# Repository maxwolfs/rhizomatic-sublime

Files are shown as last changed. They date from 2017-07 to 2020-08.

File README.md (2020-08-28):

# The rhizomatic sublime
### Searching for aesthetic transcendence in digital transience
Process and documentation of a research by [Max Wolfs](https://github.com/maxwolfs) and [Alexander Lehmann](https://github.com/bsplt).

### Rhizm

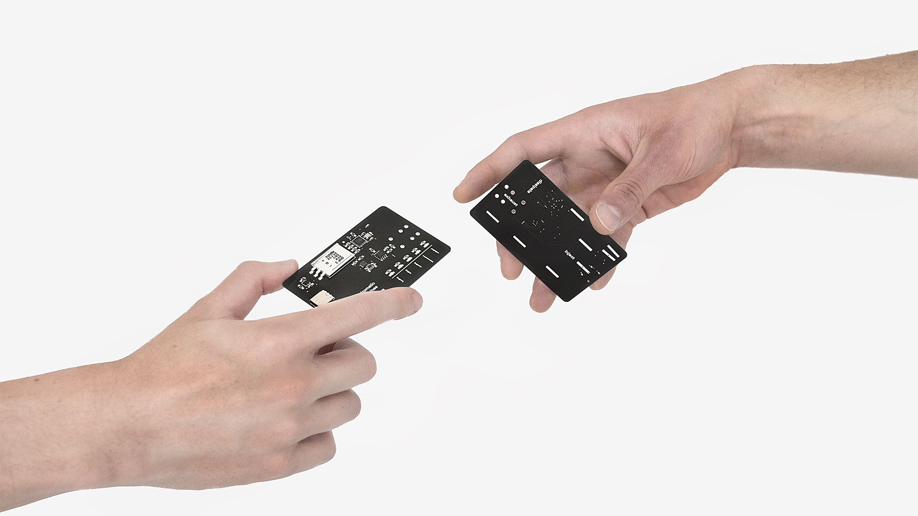
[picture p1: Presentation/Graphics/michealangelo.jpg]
Interaction


We object to the mundane paradigm of Human-Computer-Interaction and demand a Human-Human-Interaction. It's pyhsicial, it's intimate, it's exciting. Rhizm is a device in the shape of a credit card that connects over a satisfying magnetic click. Caution: Hands may touch. The connection of two cards creates a new bond in a decentralized social mesh network. Combined with a web interface that shows the verified encrypted interactions, Rhizm can be used for many different scenarios in which a physicial interaction between nodes must be safe. Or appealing. We understand our project as fundamental research in times of disbelief and scepsis among the realms of new technologies and social media. We want to commit ourselves to the power of open source platforms. Through social sandboxes like Rhizm a diverse variety of use cases such as self deployable social networks depending on real human interactions are possible.

Inject - Exhaust - Dissipate

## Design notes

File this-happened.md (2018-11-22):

# This Happened - Rhizomatic Machines

## Publikum

* Größtenteils Hamburger Werbelandschaft, Kreative, Mitte 30 bis Mitte 40
* 180 Leute + Overbooking
* Deutsch

## Konzept

* Wir objecten zu hci und demanden real hhi - why?
* dafür haben eine neue Interaktion, die ein decenztralized p2p social network established - how?
* Was ist diese Interaktion? - zwei karten klicken auf einander - cautions may touch - its intimate
* wie funktioniert die? - grafik

* Stage Test

* Das ist die Hardware -device

### Presi

1. Anekdote - Herleitung, Persönliche Stickyness zum dahinterliegenden Problem

Dass wir heute hier stehen ist das Ergebnis einer unfallreichen Verkettung von Zufällen.
[FotoMasterStudio]

2. Ausgangspunkt und Problem - Why

[lustigesBild] 
Die Welt ist voller General Purpose Devices samt bedeutungsloser, generischer Gesten.
Es ist leider nicht so wie mit Lichtschaltern, die man blind und in Dunkelheit in Räumen findet und bedienen kann. Denn die immer gleichen, absurden Bewegungen und Gesten [Absurditität mit einem Stück Holz demonstrieren] sind mit den Aktionen die sie auslösen total disconnected.

Der Lichtschalter schaltet Licht ein und aus. Ein Swipe verbindet die sexuelle Absicht zweier Personen, löscht Nachrichten, erzeugt den nächsten Screen oder lehnt den nächsten Anruf ab. Soziale Interaktionen unterscheiden sich in ihrer Bedienbarkeit nicht von Software-Funktionen. Dem Smartphone ist scheißegal ob du deine Oma wegdrückst oder ob du den Wecker stellst. Eine Virtuelle Mechanik die logisch erscheint aber dennoch frei erfunden und sich nur visuell hinter Panzerglas auf einem Bildschirm abspielt. Es ist schon lustig dass ein paar Menschen in Kaliforniern weltweit die Daumen von Milliarden von Menschen utilisiert haben.

[UnserLogoIrgendwie]
Wir widersprechen diesem mondänen HCI Paradgima und fordern eine echte HHI.
Das bedeutet auch, dass man soziale Netzwerke anders und gänzlich neu denken kann. 

3. Lösung

Deshalb haben wir eine revolutiomäre Interaktion erfunden.

It's not Multitouch
It's not Touch ID
It's not Force Touch
It's physical
It's fucking real touch

[Bild-RealTouch]

Diese Interaktion erzeugt unausweichlich ein Verbindung aus getätigten Interaktionen. Ein auf echten Berührung basiertes, denzentrales soziales Netzwerk.

[Netzwerkbild]

Facebook meint ein soziales Netzwerk auf einen Klick - einen Like reduzieren zu können - und kann die echten Emotionen nicht abbilden. Wir schon.
Ein Klick auf Freundschaftsfrage A von Person B Annehmen ist was anderes ist als wenn ich zum Zeitpunkt X an Ort Y mit Person Z Situation W erzeuge und erfahre.

[Beweisbild] Klick + Emoki vs Der echte Blick und die echte Berührung

Das geile ist dass es Awkward sein kann. Direktes echtes Feedback.

4. Wie funktioniert der Scheiß?

[Darstellung]

Jede Person hat eine einzigartige Karte. Wenn man diese aneinanderhält, ziehen sie sich an und verbinden sich.
Sie tauschen sich aus und schicken die Verbindung in die Cloud. 

5. Stage Test

www.rhizomaticmachines.com

6. Technik

[Film] Blinkende Karte

Features:

* Wifi
* Superkondensator
* USB-C
* Custom-Magnetic-Connect (Patent Pending)

7. Fazit

Wir verstehen unser Projekt als Grundlagenforschung in Zeiten von FAKE News und Skepsis im Spannugnsfeld zwischen Neuen Technologien und Sozialen Medien.
Wir geben euch den Scheiß an die Hand, ihr wisst wies funktioniert. Have fun Testing.

Inject - Exhaust - Dissipate

Achso, und wir arbeiten übrigens an Implantanten.

## Ausblick

* das digitale: etymologisch. zum finger gehörend
* implantante, egal wo am körper
* direct touch!

## TODO

* Für die Präsentation soll auf der Webseite nur der leere Graph zu sehen sein
* Webseiteüberarbeitung: 
* Passende Kleidung: 

## Story

moin wir sind alexander lehmann und maximilian wolfs. wir haben damals 2017 im master digitale medien an der hfk in bremen unser master projekt gemeinsam gestartet, mittlerweile arbeiten auch auf professioneller eben zusammen. in einem startup.

das ganze hat eignetlich angfangen im master studio bzw. in den dm studios der hfk. kurz zur hfk: 600 studierende, größtensteils freie kunst, dann design und digitale medien. der studiengang befindet sich im spannungsfeld von kunst design theorie und technologie. 

unser studio wo ba und ma gemeinsam beheimatet sind ist dabei unser ökosystem oder refugium. kreative zerstreuung, richtig krasse unordnung aber gleichzeitig das gemütlichste atelier der ganze hochschule. überall alte kaputte harware oder aber supernice coole techno artefakte mit denen man die nacht durch crazy experimente vornehmen kann. genau hier haben wir auch im zweiten semester entschieden unser master projekt zusammen zu machen. 

am anfang haben wir uns erstmal generell mit emerging technologies auseinandergesetzt die gerade so am tech horizon am aufgehen sind und haben uns erstmal die wunderbare wolkenwelt und ihre derivate der neuronale netze geschnappt. da sind wir erstmal schön in technischer unterkühlter medienkunst manier auf die atomare eben was da eignetlich so grundsätzlich passiert abgestiegen. 

da haben wir relativ fix simulationen geschrieben, protoypen gebaut mit einem recht rudimentären hardware logic gate network was 2bit informationen distributed, um  herauszufinden welches verhalten zwischen stabilität und labilität bei einer skalierung passiert und ob sich emergentes verhalten der netzwerks einstellen kann? 

ja und dann this happened...
ich hab mir meinen bei einem nächtlichen rennrad ritt den daumen ordentlich zerlegt.

versucht mal ohne daumen zu löten oder ein touch interface zu bedienen. das ist wirklich mies. man macht ja wirklich mittlerweile fast alls mit mobilen touch devices, egal ob mutti anrufen, überweisungen, texten, flüge buchen, freundschaftsanfragen verschicken, wobei ja eher jetzt eher so insta scrollen am start ist oder halt stop - schluss machen! das war dann auch der denkanstoß für rhizomatic machines.

warum ist das gestenset eines touchscreens für so viele verschiedene anwendungen und vor allem unterschiedlichste bedeutungen so unglaublich begrenzt? weil es alles maximal gleichartige industrielle massenproduzierte general purpose devices sind mit dem größten unterschied dass bei der einen der zwei betriebssystem der links swipe ein zurück bedeutet und in dem anderen ein menü ausfährt. wenn man mal genau darüber nachdenkt, ist das echt eine ziemlich beschränkte bandbreite und macht den gap zwischen dem "User" der wir alle ja irgendwie sein sollen und für den das ja alles gemacht wird und der diversität an interaktioen die wir mit unserer körperhardware und vernetzten serices so machen bzw nicht machen können ziemlich groß. der gap ist krass!

und an dem punkt objecten wir hart zu diesem HCI paradigma. Es ist schon absurd dass ein paar Menschen in Kaliforniern weltweit die Daumen von Milliarden von Menschen programmiert haben. Wir fordern an der stelle statt einem HCI eine echte HHI. Das bedeutet dann auch, dass man soziale Netzwerke anders und ganzehtilich neu denken kann.

Deshalb haben wir eine revolutionäre Interaktion erfunden!

Es ist kein Multitouch
Es ist kein Touch ID
Es ist kein Force Touch
Sondern eine echte Berührung.

Eine echte Berührung in einer echten Stiuation mit zwie Menschen die sich berühren und damit ein auf dieser Interaktion basiertes dezentrales soziales Netzwerk erzeugen.

Facebook meint ein soziales Netzwerk auf einen Klick - einen Like reduzieren zu können - und kann die echten Emotionen nicht abbilden. Wir schon. Ein Klick auf Freundschaftsfrage A von Person B Annehmen ist was anderes ist als wenn ich zum Zeitpunkt X an Ort Y mit Person Z Situation W erzeuge und erfahre. Das geile ist dass es Awkward sein kann. Es gibt direktes echtes Feedback. WOw?

Jede Person hat eine Karte mit einzigartiger ID. Wenn sich zwei Karten aneinander annähern, ziehen sie sich an und verbinden sich. Sie tauschen sich aus und schicken die Verindung in die Cloud.

Wir habens gerade noch geschafft heute vor der Präsentation die neuste Revision vom Zoll abzuholen. Schon fertig bestückt von unserem PCB manufacturer aus Shenzen. Ah, richtig gut verpackt. und? ja, die sehen doch sehr gut aus. ja geil. dann lass sie uns gleich mal testen. usb-c kabel? jo hier. alles klar. ja wir müssen erstmal den Superkondensator aufladen. knapp 15 sekunden, dann isser voll. ja zack fertig, sogar nur 10. wow sehr gut. na dann mal los. also, random situation. klack. ah moin. hehe. ups berührt. socially awkward level 5. ja sehr gut dann ist der saft jetzt verbraucht. dann ma ran an strom. usb-c uh ja. so es wird geladen, wifi login successful, es blinkt. ja übertragung läuft. bei mir auch. super und dann gucken wir mal ob was passiert. oh ja da ist es.

Tech Talk

Wir verstehen unser Projekt als Grundlagenforschung in Zeiten von FAKE News und Skepsis im Spannugnsfeld zwischen Neuen Technologien und Sozialen Medien.
Wir geben euch den Scheiß an die Hand, ihr wisst wies funktioniert. Have fun Testing.

Inject - Exhaust - Dissipate

Achso, und wir arbeiten übrigens an Implantanten.

* Video Verband auf Smartphone
* Bild Verband
* Video Blinkende Karte
* Video FB Emoji Like
* Video real Card Situation
* Video

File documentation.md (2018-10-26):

# Master Projekt Dokumentation

## by Alexander Lehmann & Maximilian Wolfs

# Abstract

# Einführung

### Die Pflanzen
### Rhizomatisch why?
### Die Neuronen und die Gates
### kollaborativ Prozess via git

# Rhizomatic Machines

## Konzept

Allgemein kann der Beschluss einen Akt des Konsums zu tätigen, einen Akt, indem man Geld gegen eine Ware eintauscht, durch eine Vielfalt von Ursachen hervorgerufen werden, die mehr oder weniger einer fiskalen Vernunft unterliegen. Knappheit von lebenswichtigen Gütern ist ein treibender Faktor, der Menschen beispielsweise dazu treibt im Supermarkt das symbolische Äquivalent ihrer Arbeitskraft für eine Fertignudelsuppe zu substituieren. Der kausale Zusammenhang Bedarf, Knappheit und Wert scheint hier trivial. Der Hunger bestimmt den Preis in Abhängigkeit vom Angebot. Interessant wird es jedoch an dem Punkt, an dem sich diese Kausalität umkehrt. Sobald ein künstlich gesetztes Preisniveau eine soziale Rechtfertigung für Verknappung oder gar den Bedarf wird, löst sich jede okonomisch sinnvolle kausale Verkettung auf. 

## Interaktion

# Technischer Hintergrund

## Das Device

### Kartenformat
### Custom PCB
### Komponenten Research
### Kicad Layoutprozess

## Website

### Idee
### Flask API
### Fullpage JS
### CSS Grid Layout
### P5JS Force Directed Graph

## Pouches

### Idee

## Riso Magazin

### Idee

# Fazit

### Intercourse Reflektion

# Future

### HEC Sponsorship
### Test Roll Out

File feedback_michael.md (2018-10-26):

# Rhizm - Feedback von Michael

Pouches sind raus

Anwendungsneutrale Technik ist gut, aber nicht bei API belassen sondern die Leute abholen

"Interaktion erfunden" ist der Fokus

"Wir können ... besser als Facebook/Google"

Statt Intercourse einen Namen für die Interaktionen finden, der so gut ist wie "googlen"

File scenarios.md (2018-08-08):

## Application Scenarios

#### Scenario 1 / Karte als Hardwareschlüssel für Router

Person A und Person B leben in Tokyo und Berlin und wollen einen privates Netzwerk aufbauen.
Sie nehmen die SChlüsselkarten aus ihrem Router und treffen sich und connecten magnetisch.
Sie stecken sie wieder in den Router und bei einem Match wird die Verbindung erzeugt.

Als Modul im Router
Zufallsdaten durch Beschleunigungssensor mit PGP
privates Netzwerk sichere Kommunikation bliebig erweiterbar
kaskadierte Sicherheitspolicy

#### Scenario 2 / Feierstein

...

#### Scenario 3 / Einsatz im Krisengebiet

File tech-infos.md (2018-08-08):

# Konsumkunst als soziales Experiment

## Karte für (social) intercourse ← wird nicht erklärt!

Single Devices with unique id– Card like format – Schlauchbeutelverpackung – social intercourse interaction
[old Presentation](https://docs.google.com/presentation/d/1cpQ3VtDt5smEuH57AWrwYjjEIkGQ9L3YSArqFy4ICfg/edit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)

#mystisch #schräg #poppig #cool

* unique interaction
* blockhain
* eindimensionales datenbank browsen
* feature entwicklung on the fly
* Spezieller Dispenser / Automat in Galerie
* dynamischer Preis gekoppelt an Aktiviät der User oder Ausgabe an globale Zeitevents
* verschiedene Auflagen / verschiedene Generationen
* (Ablaufdatum? Interaktion rettet die Karte.)

## Hardware

* USB-A Male Pins / Anschluss zum Aufladen eines superflachen Super Caps als Stromversorgung
* ESP-32 (https://tinyurl.com/yadrkr9d) sendet Daten zur Blockchain und received Verification
* Super-Cap (https://tinyurl.com/y7quk3u3) lädt sich nur bei erfolgreichem (von beiden Cards verifiziertem Intercourse) Intercourse auf. “1 Ladung pro Intercourse”
* Voltage Regulator Input: 2-5.5V Output: 2.7V
* Transistor zur Bestimmung ob Ladung des Kondensators oder Pairing
* LEDs
* Magnete
* PCB mit Siebdruck (uniqude Hash ID der cards generiert Grafik)

### BOM

-> [Mouser](https://www.mouser.com/ProjectManager/ProjectDetail.aspx?AccessID=86460eb120)

## Tech
* [ESP-32 Wroom Datasheet](https://www.espressif.com/sites/default/files/documentation/esp-wroom-32_datasheet_en.pdf)
* [Kondensator Rechner](http://www.elektronik-labor.de/OnlineRechner/Kapazitaet.html)
* [Super-Cap Tech Sheet](https://www.mouser.de/ProductDetail/81-DMF3Z5R5H474M3DA0)
* [Hardware Guidelines for super cap](https://www.murata.com/~/media/webrenewal/products/capacitor/edlc/techguide/electrical/edlc_technical_note.pdf)
* [Voltage Regulator 5V -> 2.5V](https://www.mouser.de/ProductDetail/STMicroelectronics/LD1117S25TR?qs=sGAEpiMZZMuXVhsoTePomv6abewqdBmu8)

## Wie interagieren die Teile?

* 2 - ? weiße LEDs / Statusanzeige auf Board / Approved, Denial, Serverconnection required, ... ?
* Intercourse via Magnetarretierung der Cards

## Resources / Links

#### ESP8266

* [RF PCB Layout Guidelines](http://iot-bits.com/simple-rf-pcb-layout-tips-tricks/)
* [LORA WAN Network](https://www.lora-alliance.org/)
* [ESP8266 SSL / HTTPS](https://github.com/arduino-libraries/ArduinoHttpClient/issues/13)
* [ESP8266 POST JSON -> Webserver](https://techtutorialsx.com/2017/01/08/esp8266-posting-json-data-to-a-flask-server-on-the-cloud/)
* [ESP KiCad Library](https://github.com/jdunmire/kicad-ESP8266)
* [ESP8266EX PCB Design / Layout Examples](http://www.liot.io/hardware/design/)
* __[OFFICIAL ESP8266EX Hardware Design Reference](http://akizukidenshi.com/download/ds/espressifsystems/0B-ESP8266__Hardware_User_Guide__EN_v1.1.pdf)__
* [Programming ESP8266](https://hackaday.com/2015/03/18/how-to-directly-program-an-inexpensive-esp8266-wifi-module/)
* [Example Layout by Sparkfun](https://www.sparkfun.com/products/13231) and [Schematic](https://cdn.sparkfun.com/datasheets/Wireless/WiFi/SparkFun_ESP8266_Thing.pdf)
* [Boot Mode Selection](https://github.com/espressif/esptool/wiki/ESP8266-Boot-Mode-Selection)
* [Pin Definition](https://github.com/esp8266/esp8266-wiki/wiki/Pin-definition)

#### ESP8266 FLASH / EEPROM

* [How to save variable into flash](https://github.com/esp8266/Arduino/issues/1537)
* [FLASH - User data storage](https://bbs.espressif.com/viewtopic.php?t=698)
* [Save ESP8266EX RAM with PROGMEM](https://www.espressif.com/sites/default/files/documentation/save_esp8266ex_ram_with_progmem_en.pdf)

#### Super Capacitors / LiPo / Energy Supply / Balancing

* [Murata LiPo UMAL](https://www.murata.com/~/media/webrenewal/products/smallenergydevice/umal24_datasheet.ashx?la=en-us)
* [TI BQ33100 SuperCap Controller IC](http://www.ti.com/product/BQ33100)
* [TI BQ24640 SuperCap Charger IC](http://www.ti.com/product/BQ24640)
* [High Current Supercapacitor Backup Controller IC](http://www.linear.com/product/LTC3350)
* [LTC3225 - 150mA Supercapacitor Charger](http://www.linear.com/product/LTC3225)
* [TPS6122x Low Input Voltage, 0.7V Boost Converter](http://www.ti.com/lit/ds/slvs776b/slvs776b.pdf)
* [LiPo Ladegerät mit Balancer - Eigenbau](https://fpv-community.de/showthread.php?64194-LiPo-Ladeger%E4t-mit-Balancer-Eigenbau)
* [ESP8266 LiPo Power Regulator](https://randomnerdtutorials.com/esp8266-voltage-regulator-lipo-and-li-ion-batteries/)
* [Equation for calculating supply current from caps](https://electronics.stackexchange.com/questions/240329/using-supercapacitor-as-backup-for-mcu)

#### RF Energy Harvesting

* [Murata: Supercap enables “battery-less” smart card/ID card](https://www.murata.com/~/media/webrenewal/products/capacitor/edlc/appsnote/c2m1cxs443e_appnote_smartcard.ashx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)
* [Energy Harvesting Mouser Article](https://www.mouser.de/applications/rf_energy_harvesting/)

## Data

card =  {
	“id”:”hash”,
	“value”:”int”
};

## Packaging

* [Popcorn Design](https://www.trendhunter.com/trends/microwave-popcorn-bag)

## KiCAD
* [Artworks in KiCAD](https://hackaday.io/project/18508-mr-robot-badge/log/53901-this-is-how-you-do-art-in-kicad)

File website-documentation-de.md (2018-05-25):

# DM website documentation of rhizomatic machines by Alexander Lehmann & Maximilian Wolfs

* Title: Rhizomatic Machines
* Category: Semesterarbeit
* Student/s: Maximilian Wolfs, Alexander Lehmann
* Course Title: Master Project
* Lecturer/s: Ralf Baecker, Dennis Paul
* Year: WS 2017/18

Interaction

Wir haben eine neue Interaktion erfunden.

Der aktuelle Trend digitaler Services von Shopping über soziale Netzwerke bis hin zu zivilen Institutionen besteht darin, die Dienstleistungen in Apps und Webseiten über General Purpose Devices allen voran Smartphones anzubieten. Dieses Paradigma trifft die Annahme, dass ein Interface - in diesem Falle der Touchscreen - das beste Lösung zu sein scheint. In unseren Augen ist dieser jedoch nur der kleinste gemeinsame Nenner.

Wie kann man Cloud Technologien und Digital Services bedeutungsvoll in den Alltag implementieren? Wir sind dabei auf der Suche nach einer besseren Lösung, die wir im Bereich UI und UX finden wollen. Unser Ansatz: Wir entwickeln ein sicheres IoT Wearable, das als Brücke zwischen barem Metall und der Cloud fungiert.

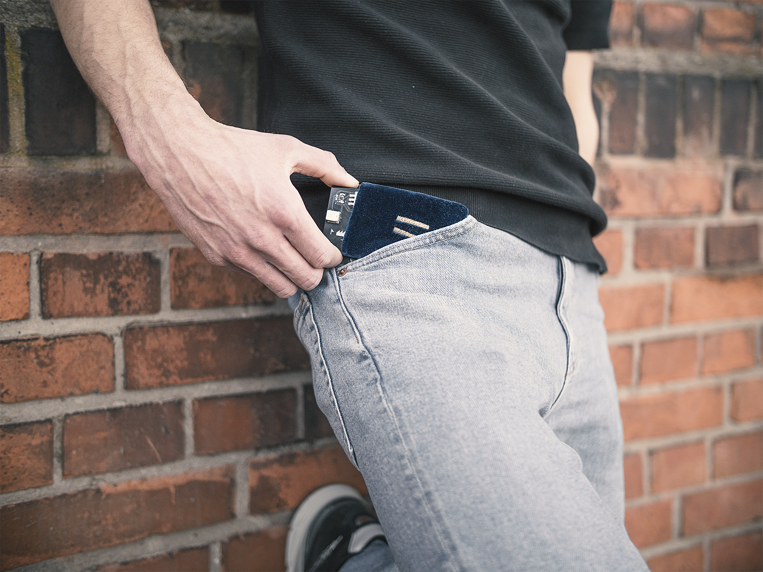
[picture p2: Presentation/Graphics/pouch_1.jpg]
everyday


Wir sehen in unserem Produkt eine soziale Sandbox, die ganzheitlich von Cryptography bis UX Design gedacht ist. Das Projekt an sich stellt in seiner Schnittmenge experimentelle Grundlagenforschung dar. Wir untersuchen Felder wie Interaction Design, Blockchain und IoT und fragen uns, wie man diese Technologien in einem sinnvolleren und vor allem bedeutungsvolleren Kontext in unserem Alltag implementieren kann. Im gegenwärtigen Konzept beschäftigen wir uns mit der Machbarkeit eines solchen Services und wollen die Möglichkeiten der Sandbox mit diversen Szenarien eruieren. So können wir uns beispielsweise Anwendungen wie ein soziales Netzwerk beruhend auf physischer Interaktion vorstellen.

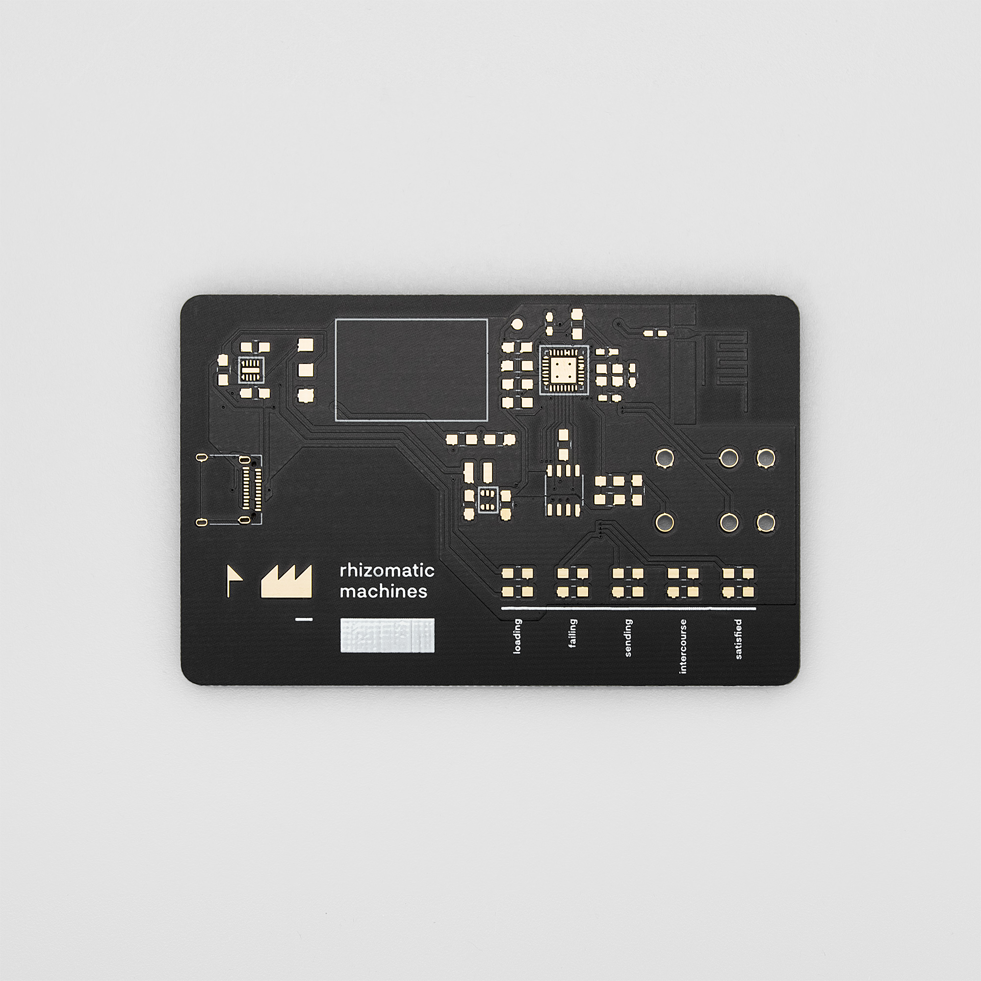
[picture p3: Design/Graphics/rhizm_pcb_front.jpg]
Front

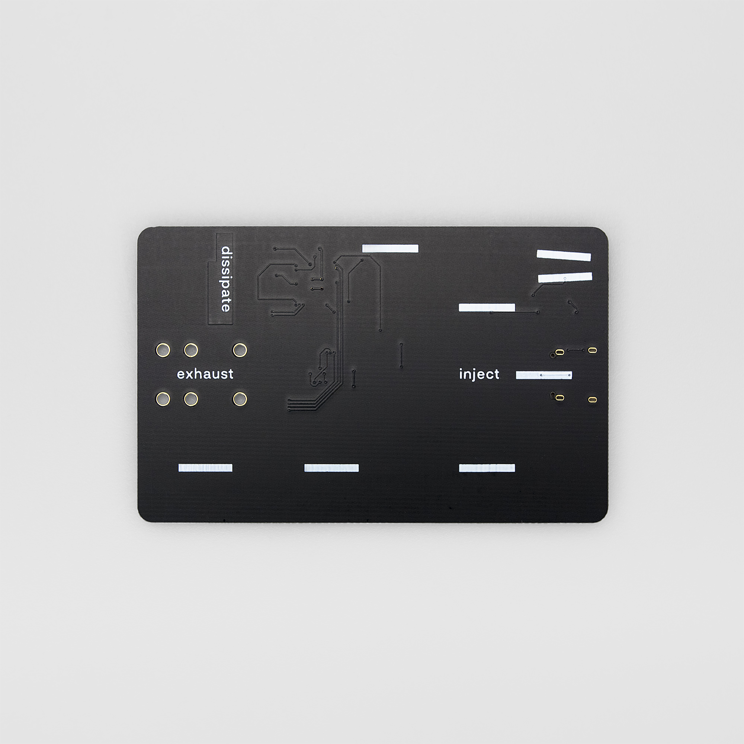
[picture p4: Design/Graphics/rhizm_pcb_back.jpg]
Back


Der aktuelle Prototyp besteht aus Karten/PCBs und einem Web Interface mit Datenvisualisierung und Datenbank. Eine Interaktion der Karten erzeugt einen Eintrag in der Cloud, der sich in einem Graphen manifestiert. Maßgeblich bestimmend für den aktuellen Zwischenstand des Projekts war eine medienkünstlerische sowie gestalterische Perspektive auf eine neue Interaktion, die eine Brücke zwischen physischer Realität und Cloud bildet. Der eigens entworfene Schaltkreis und das Layout nutzen das Medium der Platine nicht als bloßen Träger von Elektronikbauteilen, sondern formen aus ihm ein ästhetisches Artefakt. Durch diese bedeutungsvolle Aufwertung und unserer entwickelten Interaktion zweier Karten mittels selbst entwickelten Magnetkontakten entsteht darüberhinaus eine neue User Experience von Bedeutung.

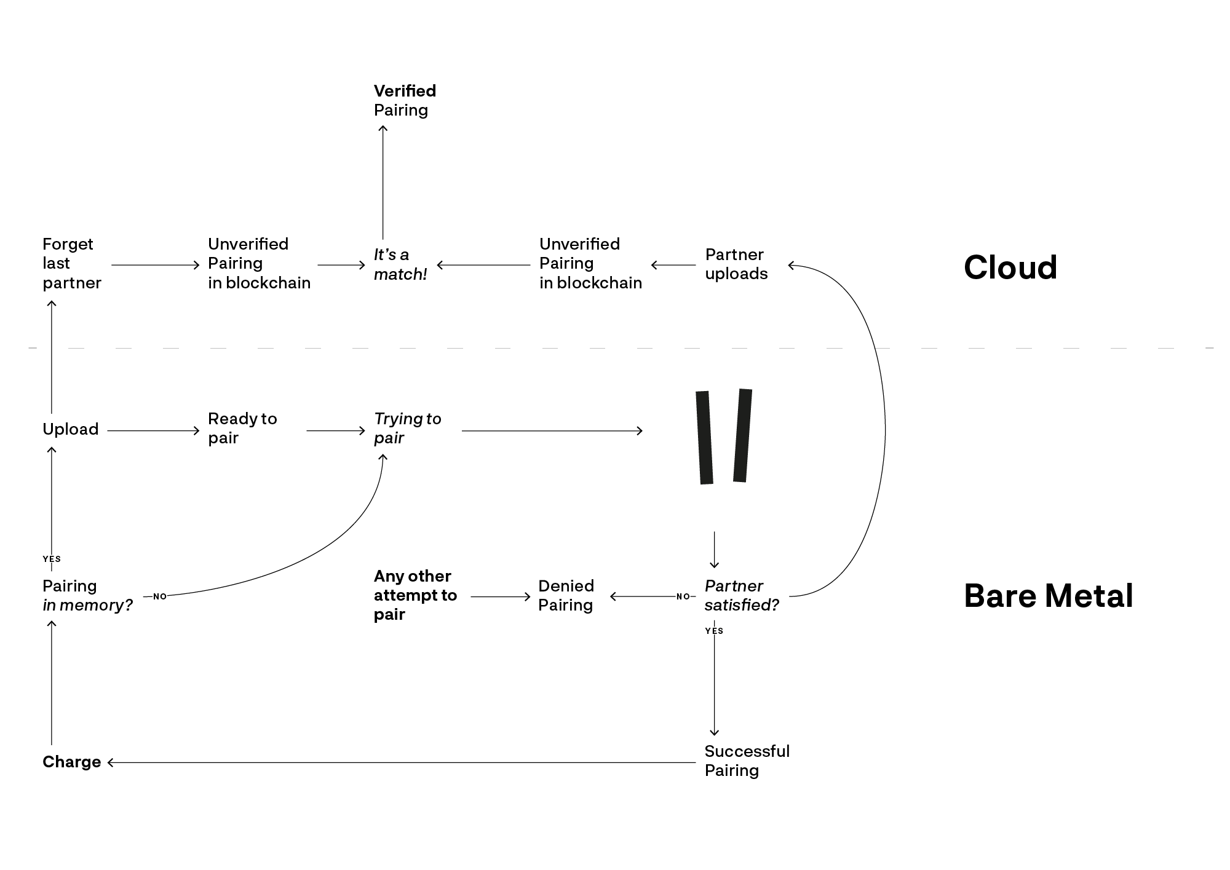
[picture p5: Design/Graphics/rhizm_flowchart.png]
userflow


Jede Karte hat eine einzigartige ID. Werden zwei Karten an ihren Magnetkontakten verbunden, wecken sie sich gegenseitig aus dem Tiefschlaf auf und tauschen über die Schnittstelle ihre IDs aus. Ein nachhaltiger Superkondensator versorgt diesen Vorgang mit Strom. Wird die Karte das nächste Mal via USB-C aufgeladen, sendet sie automatisch mit Hilfe ihrer integrierten WiFi-Funktionalität die vorher getätige Verbindung an die API. Haben dies beide Karten getan, werden die Pairing-Anfragen in der Datenbank als verifiziert gesetzt. Eine Visualisierung aller verifizierten Kartenpairings ist auf der Hauptseite http://www.rhizomaticmachines.com zu sehen.

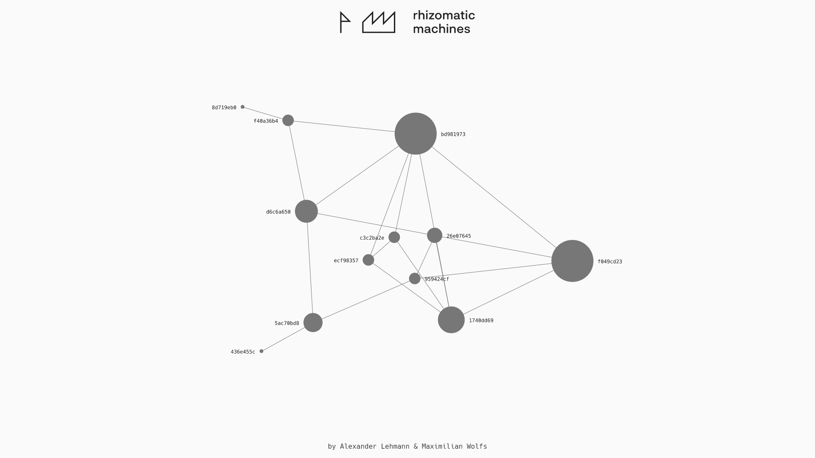
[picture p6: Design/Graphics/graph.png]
graph


Im grafischen Interface wird jede Karte durch einen Kreis mit relationalen Verbindungen dargestellt. Je größer die Punkte, desto mehr verifizierte Pairings hat die Karte zu verzeichnen. Zu sehen ist also eine Karte aller gerade bestehenden Prototypen und ihrer Pairing-Aktivitäten. Ein Mesh sozialer Interaktionen.

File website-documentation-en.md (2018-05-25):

# DM website documentation of rhizomatic machines by Alexander Lehmann & Maximilian Wolfs

* Title: Rhizomatic Machines
* Category: Semesterarbeit
* Student/s: Maximilian Wolfs, Alexander Lehmann
* Course Title: Master Project
* Lecturer/s: Ralf Baecker, Dennis Paul
* Year: WS 2017/18

Interaction

We invented a new interaction.

The current trend in digital services, from shopping to social networking and civil institutions, is to offer services in apps and websites via general-purpose devices, especially smartphones. This paradigm makes the assumption that an interface - in this case the touch screen - seems to be the best solution. In our eyes, however, this is only the lowest common denominator.

How can you implement cloud technologies and digital services meaningfully into everyday life? We are looking for a better solution that we want to find in the area of UI and UX. Our approach: We develop a secure IoT wearable that acts as a bridge between bare metal and the cloud.

everyday

We see in our product a social sandbox that is holistically conceived from cryptography to UX design. The project itself is an intersection of basic experimental research. We explore fields such as interaction design, blockchain, and IoT, and ask ourselves how to implement these technologies in a more meaningful and, above all, more meaningful context in our everyday lives. In the current concept, we are concerned with the feasibility of such a service and want to explore the possibilities of the sandbox with various scenarios. For example, we can think of applications like a social network based on physical interaction.

Front
Back

The current prototype consists of cards / PCBs and a web interface with data visualization and database. An interaction of the maps creates an entry in the cloud that manifests itself in a graph. The decisive factor for the current status quo of the project was a media-artistic and creative perspective on a new interaction, which forms a bridge between physical reality and the cloud. The specially designed circuit and layout do not use the board's medium as a mere carrier of electronic components, but shape it into an aesthetic artifact. This significant enhancement and our developed interaction of two cards using self-developed magnetic contacts also creates a new user experience of importance.

userflow

Each card has a unique ID. If two cards are connected to their magnetic contacts, they awaken each other from deep sleep and exchange their IDs via the interface. A sustainable supercapacitor supplies power to this process. The next time the card is charged via USB-C, it automatically sends the previous connection to the API using its built-in WiFi functionality. If both cards have done so, the pairing requests in the database will be set as verified. A visualization of all verified card pairings can be seen on the main page http://www.rhizomaticmachines.com.

graph

In the graphical interface, each map is represented by a circle of relational connections. The larger the points, the more verified pairings the card has. You can see a map of all existing prototypes and their pairing activities. A mesh of social interactions.

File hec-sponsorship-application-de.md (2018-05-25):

# Application for HEC Sponsorship 2018

# Rhizomatic Machines

Interaction

Wir haben eine neue Interaktion erfunden.

## Hintergrund und Konzept

Der aktuelle Trend digitaler Services von Shopping über soziale Netzwerke bis hin zu zivilen Institutionen besteht darin, die Dienstleistungen in Apps und Webseiten über General Purpose Devices allen voran Smartphones anzubieten. Dieses Paradigma trifft die Annahme, dass ein Interface - in diesem Falle der Touchscreen - das beste Lösung zu sein scheint. In unseren Augen ist dieser jedoch nur der kleinste gemeinsame Nenner.

Wie kann man Cloud Technologien und Digital Services bedeutungsvoll in den Alltag implementieren? Wir sind dabei auf der Suche nach einer besseren Lösung, die wir im Bereich UI und UX finden wollen. Unser Ansatz: Wir entwickeln ein sicheres IoT Wearable, das als Brücke zwischen barem Metall und der Cloud fungiert.

Wir sehen in unserem Produkt eine soziale Sandbox, die ganzheitlich von Cryptography bis UX Design gedacht ist. Das Projekt an sich stellt in seiner Schnittmenge experimentelle Grundlagenforschung dar. Wir untersuchen Felder wie Interaction Design, Blockchain und IoT und fragen uns, wie man diese Technologien in einem sinnvolleren und vor allem bedeutungsvolleren Kontext in unserem Alltag implementieren kann. Im gegenwärtigen Konzept beschäftigen wir uns mit der Machbarkeit eines solchen Services, wollen aber mit Hilfe des Sponsorships die Möglichkeiten der Sandbox mit diversen Szenarien eruieren. So können wir uns beispielsweise Anwednungen wie ein soziales Netzwerk beruhend auf physischer Interaktion vorstellen.

## Stand der Dinge

Im letzten Semester haben wir haben einen funktionsfähigen Prototypen entwickelt. Er besteht aus Karten/PCBs und einem Web Interface mit Datenvisualisierung und Datenbank. Eine Interaktion der Karten erzeugt einen Eintrag in der Cloud, der sich in einem Graphen manifestiert. Maßgeblich bestimmend für den aktuellen Zwischenstand des Projekts war eine medienkünstlerische sowie gestalterische Perspektive auf eine neue Interaktion, die eine Brücke zwischen physischer Realität und Cloud bildet. Der eigens entworfene Schaltkreis und das Layout nutzen das Medium der Platine nicht als bloßen Träger von Elektronikbauteilen, sondern formen aus ihm ein ästhetisches Artefakt. Durch diese bedeutungsvolle Aufwertung und unserer entwickelten Interaktion zweier Karten mittels selbst entwickelten Magnetkontakten entsteht darüberhinaus eine neue User Experience von Bedeutung.

userflow

Jede Karte hat eine einzigartige ID. Werden zwei Karten an ihren Magnetkontakten verbunden, wecken sie sich gegenseitig aus dem Tiefschlaf auf und tauschen über die Schnittstelle ihre IDs aus. Ein nachhaltiger Superkondensator versorgt diesen Vorgang mit Strom. Wird die Karte das nächste Mal via USB-C aufgeladen, sendet sie automatisch mit Hilfe ihrer integrierten WiFi-Funktionalität die vorher getätige Verbindung an die API. Haben dies beide Karten getan, werden die Pairing-Anfragen in der Datenbank als verifiziert gesetzt. Eine Visualisierung aller verifizierten Kartenpairings ist auf der Hauptseite http://www.rhizomaticmachines.com zu sehen.

graph

Im grafischen Interface wird jede Karte durch einen Kreis mit relationalen Verbindungen dargestellt. Je größer die Punkte, desto mehr verifizierte Pairings hat die Karte zu verzeichnen. Zu sehen ist also eine Karte aller gerade bestehenden Prototypen und ihrer Pairing-Aktivitäten. Ein Mesh sozialer Interaktionen.

## Ziel

Der Fortschritt des Projekts ist stark an finazielle Möglichkeiten gekoppelt. Unser Wunsch ist es, mit dem HEC Sponsorship eine kleine Auflage unserer Karten produzieren zu können, damit wir die Funktionalität und Relevanz an einer Testgruppe wissenschaftlich evaluieren können. Ferner würden wir uns freuen den Vorgang zusammen mit HEC als Tech Insider eruieren zu können.

## Budget

| Position | Betrag |
| --- | --- |
| PCBs | 300€ |
| Komponenten | 800€ |
| Werkzeuge | 200€ |
| Hosting/Server | 200€ |
| **Summe** | **1500€** |

## Roadmap

| Zeitraum | ToDo |
| --- | --- |
| Mai | Grundlagenforschung, Realigning, Verständnis der Technologien vertiefen |
| Juni - Juli | Redesign |
| Juli - August | Test Phase and Evaluation |
| September | Evaluation |

## Fotos

everyday
Karte

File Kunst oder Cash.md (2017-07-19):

## Kunst oder Cash

ein Show-Spektakel das den spätkapitalistischen Anspruch von Kunst als authentisches, einzigartiges Aura-haftes gegen das Warenhafte, auf den Tauschwert reduziertes Objekt ausspielt.
eine kurzzeitige Plattform, die das oftmals knappste Gut und wichtigste Ressource postmoderner Künstlertypen bereittstellt: Aufmerksamkeit.
eine klassische zyklenhafte Dramaturgie.
eine partizipative Performance.

### Plot

Was ist Kunst? Wie wird Kunst?
Bei "Kunst vs Cash" handelt es sich um eine Auktion im Show Format. Es werden zwei Werke von an deutschen Kunsthochschulen eingeschriebenen Studierenden
ausgewählt und auf der Webseite gegenübergestellt. Auf diese kann nun geboten werden. Ist die Zeit abgelaufen, wird das mit dem höheren Preis gewertete
Kunstwerk an den höchstbietenden verkauft. Das andere Artefakt wird hingegen zertört. Beide Objekte befinden sich zur Zeit der Auktion in einer Galerie,
eingebettet in den Zestörungsmaschinen. Ein Live Stream überträgt die jeweils beiden Objekte auf die Webseite. Bei abgelaufener Zeit wird, das
Objekt mit dem niedrigeeren Gebot unmittelbar von der Maschine in einem langen, qualvollen Prozess zerstört. Die Zerstörungsmaschine ist dabei
an das Objekt angepasst. So könnte es beispielsweise bei klassischen Gemälde um eine Säuredusche handeln, bei elektronischen Installationen hingegen
mechansiche Pressen. Das gewinnende Objekt wird für den gebotenen Preis an den Höchstbietenden verkauft und wechselt den Besitz. Der Produzent bekommt
das Geld. Das zerstörte Objekt hingegen bleibt in der Galerie, in einer merkwürdigen Symbiose mit der Zerstörungsmaschine, ein Remix.
Seine vormalige Existenz ist nunmehr ein Mythos, der in unnahbarer Ferne liegt. Der Geist geht über in eine Aura in den heiligen Hallen der Galerie.

### Die Zutaten:

1. Das Webinterface

Die Webseite ist vom Aufbau sehr minimalistisch. 16:9 Format. Links und rechts jeweils ein quadratisches LIVE Video der beiden Objekte inkl. ihrer
jeweiligen Zerstörungsmaschine aus der Galerie. Darunter jeweils ein großer Button zum Abgeben des Gebots (in fest vorgegeben € Schritten?).
Das Webinterface muss mit dem Smartphone bedienbar sein. Je näher sich die Auktion ihrem Ende nähert, wird die Webseite unruhiger, um die
Spannung einem Spektakel gerecht zu verstärken.

Audio: Live Kommentar?

2. Die Galerie

Die Galerie agiert als Auraverstärker. Kunststudierende stellen (noch) keine Künstler dar. Zu Kunst werden Objekte nicht einfach so, sondern
werden zu solche gemacht. Dieses Machen von Kunst geschieht durch Institutionen, die dazu legitimiert sind. Dazu gehören Galerien, bestimmte Personen
oder beispielsweise ein Diskurs.

3. Die Zerstörungsmaschinen

Die Zertörungsmaschine scheint zunächst paradoxes Produkt in der Logik eines kapitalistischen Systems. Eine Maschine dient normalerweise der Produktion,
um Waren nicht für ihren Gebrauchswert, sondern für ihren Tauschwert zur Kapitalakkumulation herzustellen. In einer Ökonomie die auf Wachstum basiert ist
hingegen der Verbrauch und Verschleiß von Produkten notwendig, damit immer neu gekauft wird. Insofern scheint sie jedoch die perfekte negative Maschine.
Hat die Zerstörungsmaschine das Objekt mit dem niedrigeren Objekt zerstört, verschmilzt es auf eigenartige Weise mit ihm zu etwas Neuem, möglicherweise
Kunst.

### Dramaturgie / Ablauf:

1. Vorspiel

Im Vorspiel wird zum Aufbau der Stimmung für den letztlichen Akt der Zerstörung bzw. dem Zustandekommen eines Tauschgeschäfts eine Ausschreibung
zur Auswahl der beiden Künstler*innen und deren Werke stattfinden. Evtl. auch eine Abstimmung zur Partizipation der Zuschauer (eventuelle Identifikation
als Hochschule mit dem Abgesandten). Es werden jeweils ein Portrait/Videobeitrag gedreht zur Person und Arbeit im jeweiligen Dunstkreis des Wirkens und Entstehung.
Dabei werden auch gleichzeitig die Werke abgeholt und in die Galerie transportiert.

2. Spektakel

Beim Spektakel handelt es sich um den bedeutungsgebenden Moment. Auf ihn läuft alles zu.

3. Tausch und Zerstörung

(TO DO)

### Akteure / Elemente / Räume

1. Die Initatoren

Dabei handelt es sich um Maximilian Wolfs und Alexander Lehmann.

2. Zwei Künstler*innen

Bei den Kunststudierenden werden die 15min of Fame herausgekitzelt. Die für beide passierenden 15min of Fame räumen beide ab.
Doch wer erntet die Aura des Künstlers eines zerstörten eigenen Werks und wer geht den Handel ein?
Der Künstler: Der Archetypus des modernen Künstlers, seine ihm zugeschriebenen Eigenschaften wie perfekt für den im Spätkapitalismus
herrschenden immer schnelleren und Warengesättigten Markt. Flexibel und dynmaisch, anpassungsfähig und mobil. Das kreative Subjekt,
als alltagsemitorischer Experte kann mit diesen Eigenschaften besser wie kein anderes auf dem Arbeitsmarkt im Projektteam großer Konzerne
selbst kontrolliert und selbst optimiert brillieren brillieren. Doch was passiert mit dem Kunststudenten? Wird aus ihm ein Künstler?
Wie, wo es doch so viele von ihnen gibt? Auf der Suche nach Relevanz und Stil.

3. Zwei Kunstwerke...

... die noch keine sind. Ob sie zu solchen werden? Doch nur das eine? Wichtig ist, dass sie von Bedeutung für ihre Schöpfer sind und
die Eigenschaft bzw. das Potenzial zum Einzigarten im Hier und Jetzt mitbringen.

4. Die Zerstörungsmaschine

(TO DO)

5. Galerie

Die kooperierende Galerie ist von eklatanter Bedeutung, da sie das kulturelle Kapital zu Verfügung stellt.

6. Der Raum

Austragungsort und Datum für die erste Auktion sollen die Hochschultage im Februar 2018 der Hochschule für Künste Bremen sein.

### Hintergrund / Manifest

(TODO)

### theoretisches Backlog

Künstler -> Management
Kulturindustrie - Aufklärung als Massenbetrug: Kulturobjekte: Gebrauchswert verschiebt sich vollständig zum Tauschwert

### Fragen

Ob die Verschiebung bei beiden Objekte so passiert wie angedacht, ist natürlich nicht sicher.
Das Projekt ist daher als Experiment bzw. Versuchsaufbau mit klar definiertem Ablauf zu verstehen.

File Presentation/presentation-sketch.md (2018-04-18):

## presentation 1: the cheesy startup

Here at Rhizomatic Machines we think of Design & Technology not being tools that make the world a better place but make the world a more joyful place via meaningful interactions.

From the beginning we thought:
What if blockchain could do something useful? Not only being another futuristic specualtive asset or a senseless yet playful meaningful game like cryptokitties. What if we could contribute to the dilemma of social networks being actually antisocial bubble builders.

## presentation 2: cheesy fog 

Imagine a world where you can be absolutely sure about your intercourse.
Rhizm is a new way to conduct intercourse with others. A seductive yet socially awkward moment to connect.

Wanna buy it? 
Visit us at stand 1 at the entrance of segment 7.

## presentation 3: more truthful about what we want

Hello, We are Max and Alex from Rhizomatic Machines.
We have developed a new seductive collectible that enables you to conduct intercourse with others you have never met before.

The device itself is a custom designed PCB with the latest technology available on the market.

* Secure & encrypted
* WiFi
* Supercapacitor Power Supply
* USB-C
* IoT
* Blockchain

The device is focused on the Intercourse as the main interaction. How does it work?

Get a Rhizm card with an unique ID at one of our disposal machines or online at www.rhizomaticmachines.com. Find others and intercourse with them. If you found out that another person also has a Rhizm, you can perform the intercourse while holding both cards to each other. The magnetic contacts will let them snap together automatically.

This triggers each card to wake up from sleep mode and interchange their unique IDs which are saved to the card's storages. The successful intercourse triggers the lights that will create a satisfactory firework which draws all the available current from the supercapacitor.

Once the card is loaded again through its USB-C connector via your smartphone, computer or power adapter, it will automatically commit the intercourse to our API that stores a request in the database. If both cards have done that successfully the Intercourse is verfied and will be displayed in a visualization of every verfied intercourse at www.rhizomaticmachines.com.

This testifies a physical connection between two Rhizm cards which is secure and unique.

There is also a cooldown time with cards that had intercourse before in order to prevent Grinding and propagate social interactions with people you have never met before.

Each Card comes with a handcrafted velvet pouch.

Experience our prototpye at our Stand in the exhition space in Segment 7.

#### our plan/ideas for the future

* feature development and ruleset via continous delivery on the fly.
* unique editions with individual generative silkscreen design
* Hot Button Mode: Expiration date! Interaction saves card from extinction

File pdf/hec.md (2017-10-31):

# Rhizomatic Sublime

Von Maschinen die Natur sein wollten
Maximilian Wolfs / Alexander Lehmann

## Concept

A meadow of elephant grass (miscanthus rhizomen) sways in airy currents.
Embedded in the green thicket machinic imitations of grass try to hide their
mechanical otherness. They are tricky, mimicking their natural environment.
Lurking for their conspecifics, the agents are searching for patterns, for
information that reveals exceptional artificiality in their surrounding.

Agents punish their rhizomaticly connected cohabitants for misbehavior, the
ones diverging from the natural normal. An artificial species tries to vanish
in sensorial noise, leaving behind their machine-like corporeality, becoming
sublime.

The noise of whispering leaves sets emerges from the moving meadow.
Agents try to mimic natural movement of grass.
Their aim:

I.	 Mimicry. Disappear in Nature.
II.	 Identification. Eliminate Otherness.
III.	 Evolution. Spread knowledge to the rhizome.

Noise as non-signal and noise as sound: synaesthesia.

## Background

With Machine Learning evolving uncanny, hard to grasp technology that is also beginning 
to change the boundaries of what we can achieve intellectually
and nature being pushed back more and more our cultural environment, the diversity of lifeforms 
is reduced dramatically. In this setting we implement our poetic fiction of machines desiring to
act as nature, a plant and not as robotic worker in the duty of mankind.

## Installation

The final result will be an installation, 
a hybrid landscape constituted by machinic agents and plants.

## Why do we need Funding

The project is divided into to pars concerning the involved technologies: 
Machine Learning and Electro-mechanical Agents, software and hardware.
With the software being open source, the hardware for multiple agents produces
a high demand for parts that will be the subject of funding.

## Roadmap

Month | What 
--- | --- 
November | Nitinol Material Experiment
December - January | Agent Prototyping & Machine Learning Model
February | Exhibition setup prototype
March | Tweaking and Testing
April | Final installation

## Budget

Material | €
--- | --- 
Nitinol Wire + Equipment | 300 €
Plants | 400 €
Fans | 200 €
Wires, etc. | 100 €
Electronics | 500 €

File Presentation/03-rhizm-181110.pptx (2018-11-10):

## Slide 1

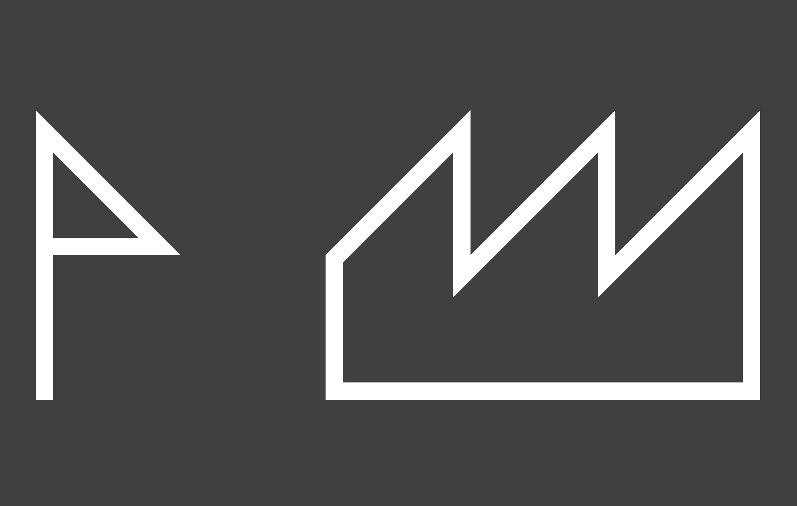
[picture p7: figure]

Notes: [Max] … we are the creators of RM

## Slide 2

- We have invented an interaction.

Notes: [Alex] Let’s us give you the core idea in two sentences

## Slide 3


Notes: [Max]
Social networks are boring
Until now there is no real life application for blockchain
So we wanted to create a physical bridge to the internet.
But with latest hi-tech and cutting edge design.
That‘s where rhizm is situated.

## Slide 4

- From bare metal to the cloud.
- A full stack high end design solution.

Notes: [Alex]
The device itself is a custom designed PCB with the latest technology available on the market.
* Custom magnet connector
* Secure & encrypted transfer and storage of the data
* WiFi
* Supercapacitor Power Supply
* USB-C
* IoT
Blockchain
RoHS

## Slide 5

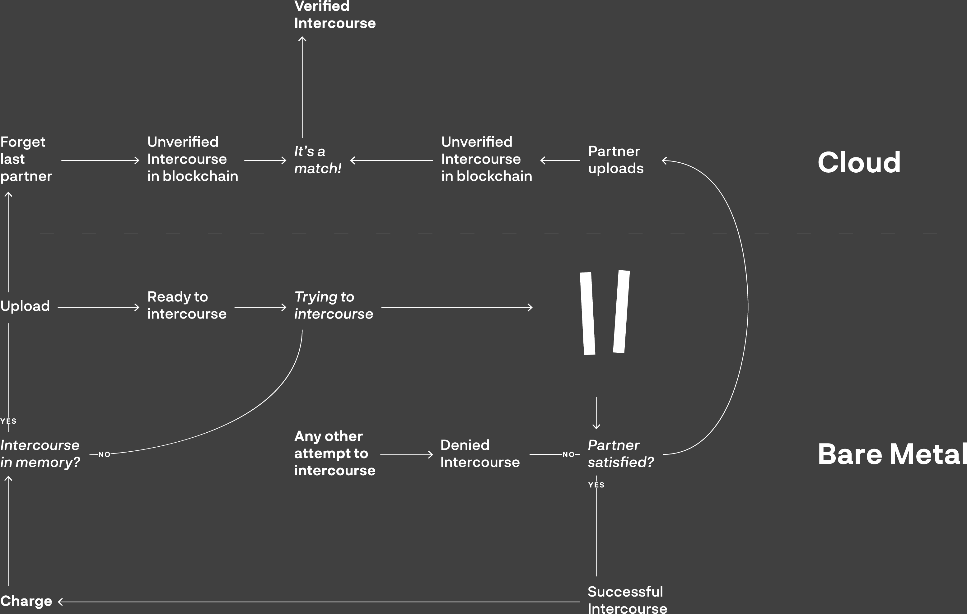
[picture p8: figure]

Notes: [Max]
Talk about complexity

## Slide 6

- Witness the first public interaction:
- www.rhizomaticmachines.com

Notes: [Alex]
Call audience for going on website

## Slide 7

- Let’s talk business for a moment.

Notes: [Max]

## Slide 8

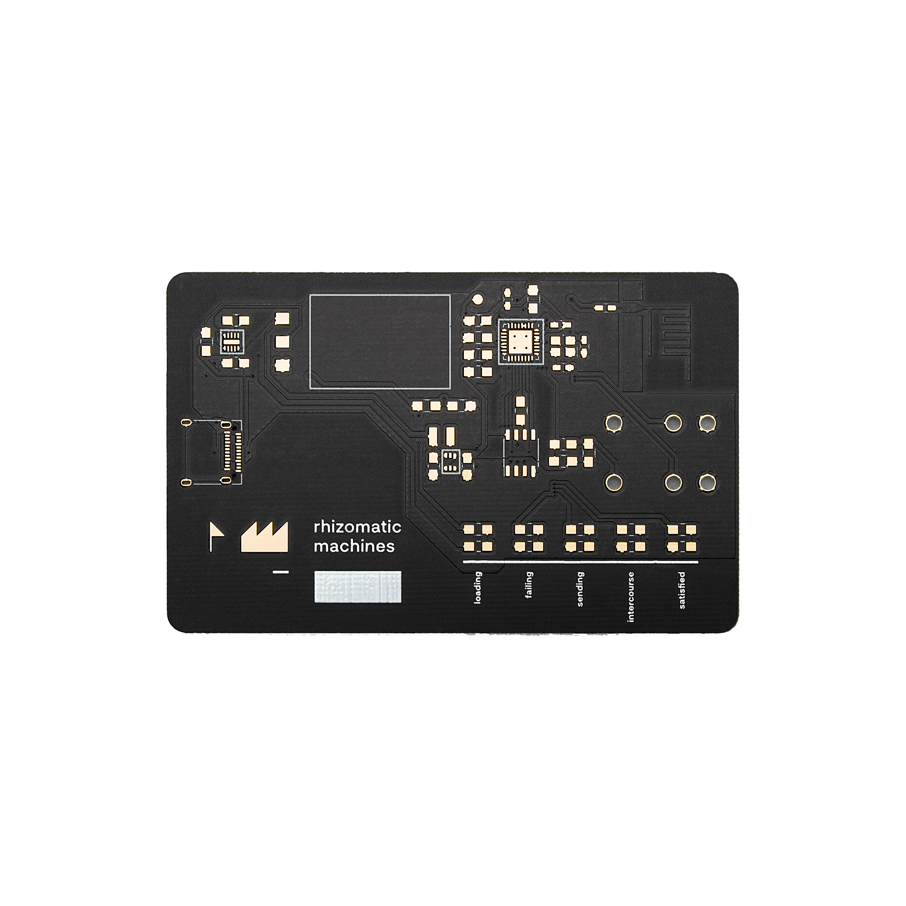
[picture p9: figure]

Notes: [Max]
Rev 3
Tech talk
High end:
Supercap
Magnets
Wifi
Credit card size

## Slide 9

- Social sandbox.

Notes: [Alex]
We understand our project as fundamental research in times of disbelief and scepsis among the realms of new technologies and social media.
We want to commit ourselves to the power of open source platforms.
Through social sandboxes like Rhizm a diverse variety of use cases such as self deployable social networks depending on real human interactions are possible.

Inject - Exhaust - Dissipate

Sandbox – This is what we do.
Explain possible use cases:
Collectible / Game
Offline interaction secure data transfer
Open source social network (you have to keep track of the hashes)
Social tiers for very well connected people (like in Black Mirror)
Everything involving mesh network connections

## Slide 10

W E F U T U R E

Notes: [Alex]
Milestone reached
Small batch production
Evaluation
Publicity
Mass Production

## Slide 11

- Thank you.

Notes: [Max]
Thank our friends and supervisors
And all the nice werkstattleiters

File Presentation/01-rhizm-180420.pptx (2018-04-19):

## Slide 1


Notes: … we have created an enterprise

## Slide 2

- We have invented an interaction.

It’s called intercourse.

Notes: Let’s us give you the core idea in two sentences

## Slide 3

- // Michelangelo shot

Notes: What do we believe in?
Motivation talk

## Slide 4

- From bare metal to the cloud.
- A full stack high end design solution.

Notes: The device itself is a custom designed PCB with the latest technology available on the market.
* Secure & encrypted
* WiFi
* Supercapacitor Power Supply
* USB-C
* IoT
Blockchain
RoHS

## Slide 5


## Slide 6

- Witness the first public intercourse:
- www.rhizomaticmachines.com

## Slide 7

- Let’s talk business for a moment.

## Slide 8

- Social sandbox.

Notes: Sandbox – This is what we do.
Explain possible use cases:
Collectible / Game
Offline interaction secure data transfer
Open source social network (you have to keep track of the hashes)
Social tiers for very well connected people (like in Black Mirror)
Everything involving mesh network connections

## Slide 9

- // PCB Closeups

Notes: This is what we offer.
Explain components and manufacturing process

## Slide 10

- // Pouch & Cables

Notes: This comes with the product.
Eco system
Pricing model

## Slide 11

W E F U T U R E

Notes: Milestone reached
Small batch production
Evaluation
Publicity
Mass Production

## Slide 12

- Visit our booth in Segment 7.
- Thank you.

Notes: Thank our friends and supervisors

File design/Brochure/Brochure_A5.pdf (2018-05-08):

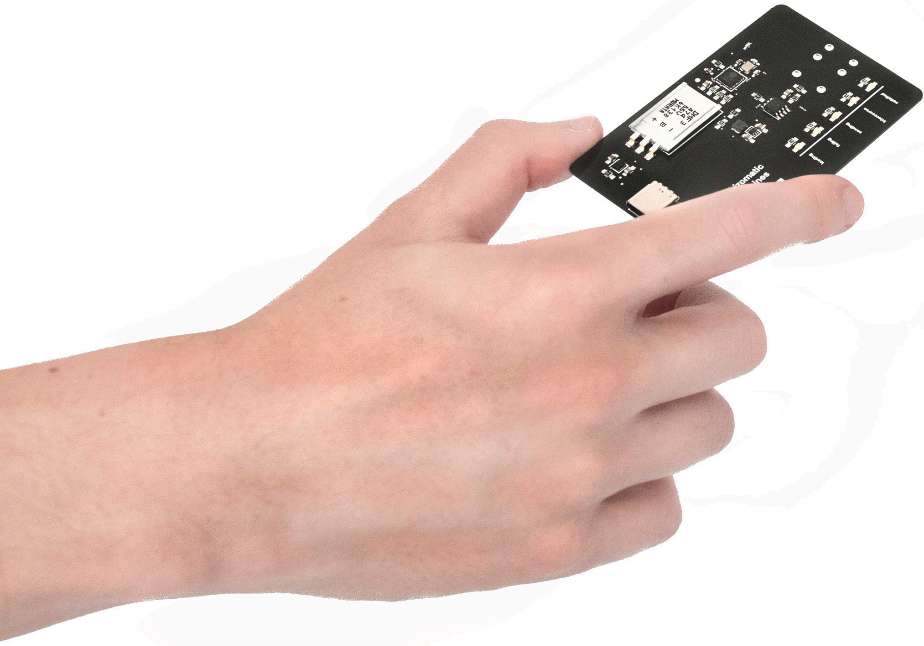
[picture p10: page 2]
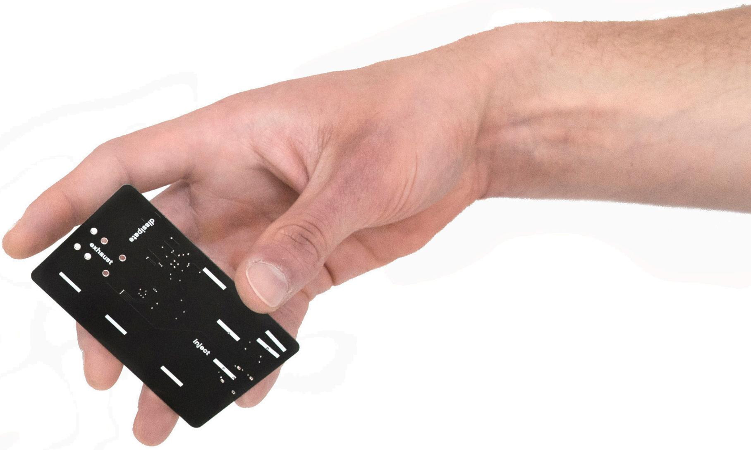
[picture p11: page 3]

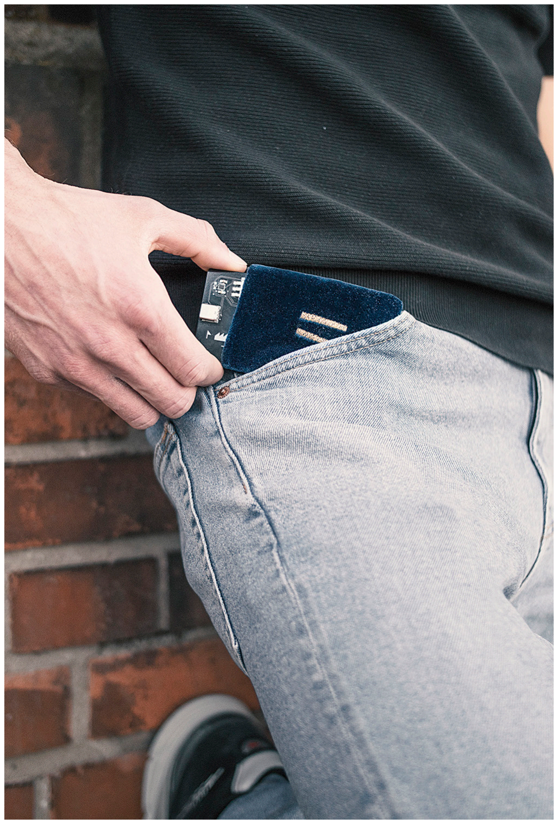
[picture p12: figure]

## rhizm

What if blockchain could do something useful? What if we could contribute to the dilemma of social networks being an unsecure and boring space? We have invented rhizm - a physical smart card with high-end technology and cutting edge design inhaling the spirit of the future - free and decentralized.

## a new interaction

Rhizm creates a rhizomatic network, a social sandbox via an all new interaction called intercourse. Every card is unique due to its id in the rhizm blockchain. Meet partners, conduct intercourse and push it to the cloud. Once both partners have done that, the intercourse wil
be cryptographically verified.

## from bare metal to the cloud

At rhizomaticmachines.com you will find all verified intercourses creating a graph that visualizes the diversity and complexity of social interactions. Free your mind and play around with our public API creating your own experience with rhizm. Customize your rhizm and invent unforeseen applications to make the world a better place.

loading

finding

sending

Cloud

## rhizm use flow

supercapacitor

charger

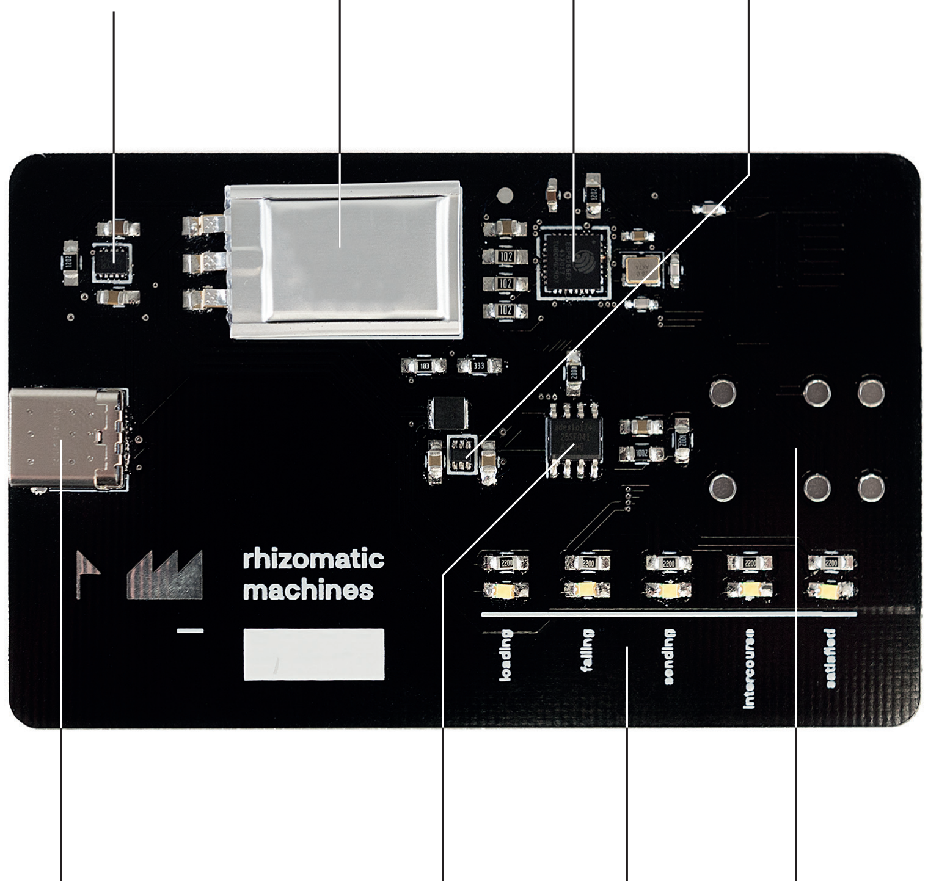
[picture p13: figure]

USB-C | magnetic connector

status
indicator

memory

microcontroller

transformer

## rhizm electronical layout

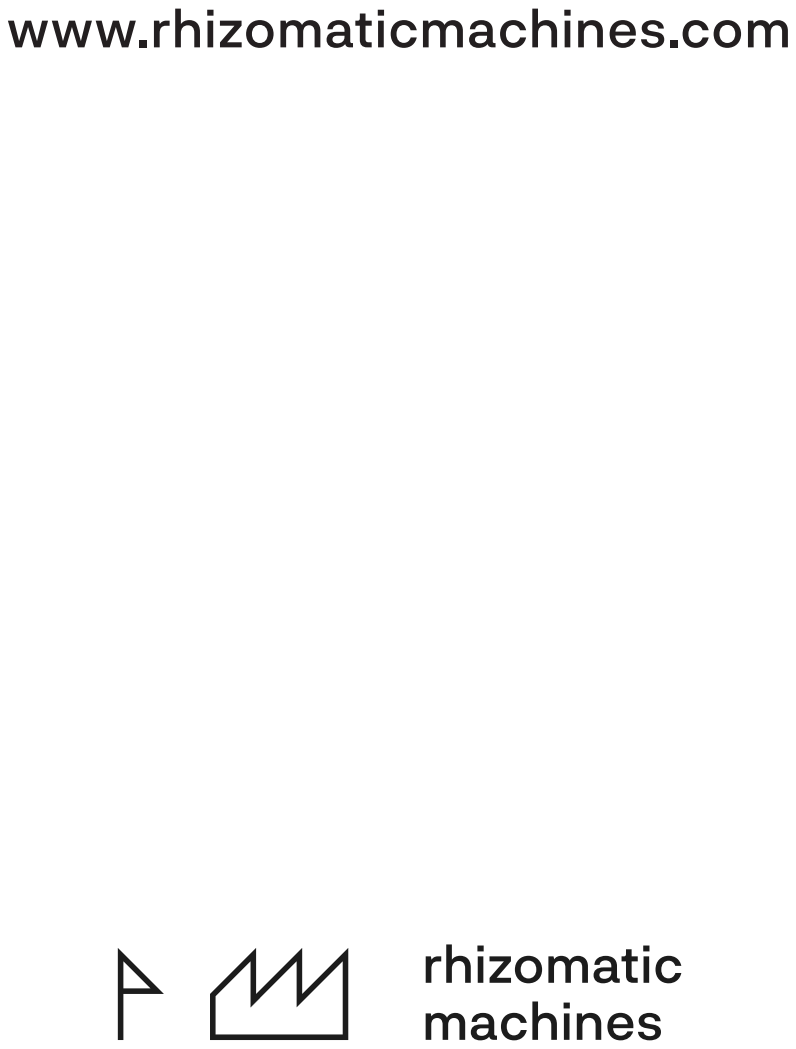
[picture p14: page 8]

www.rhizomaticmachines.com

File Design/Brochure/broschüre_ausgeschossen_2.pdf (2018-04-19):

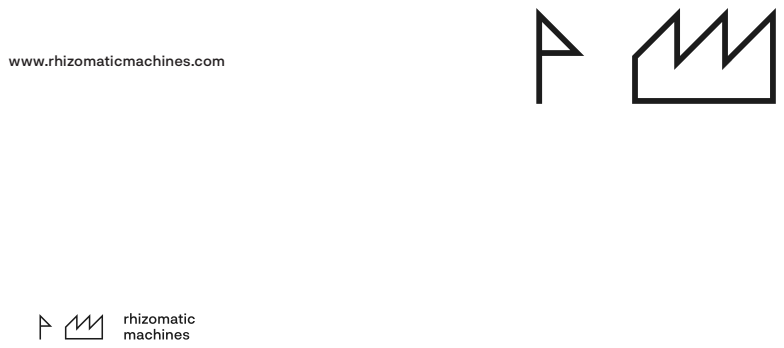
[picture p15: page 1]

www.rhizomaticmachines.com

## rhizm electronical layout

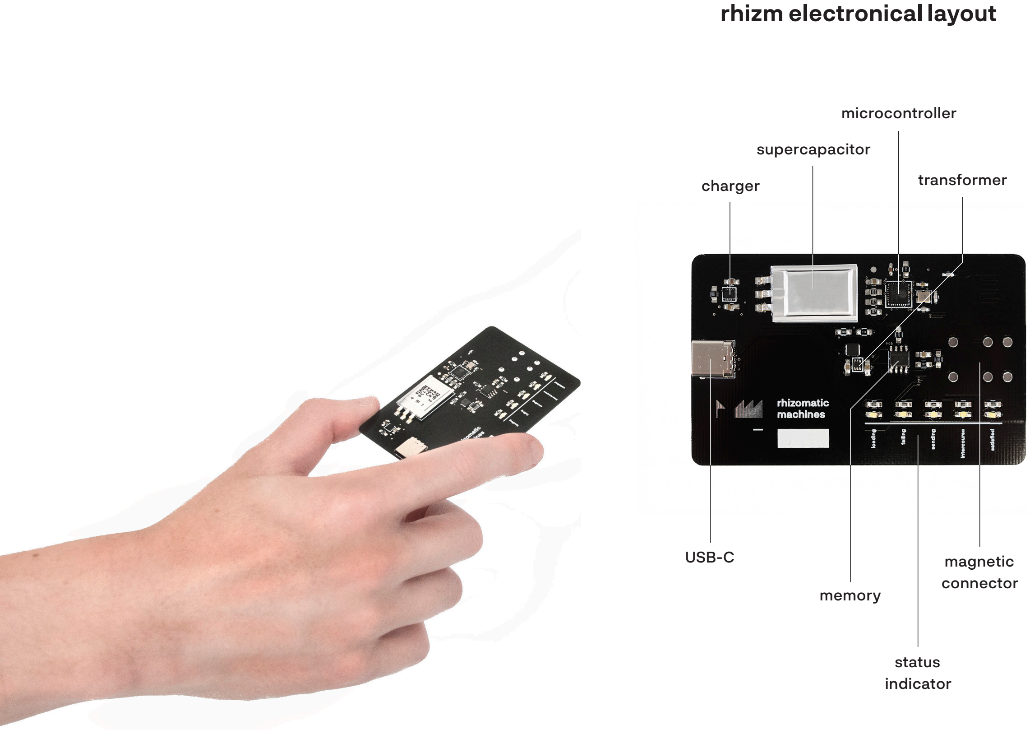
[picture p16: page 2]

supercapacitor

charger

USB-C | magnetic connector

status
indicator

memory

microcontroller

transformer

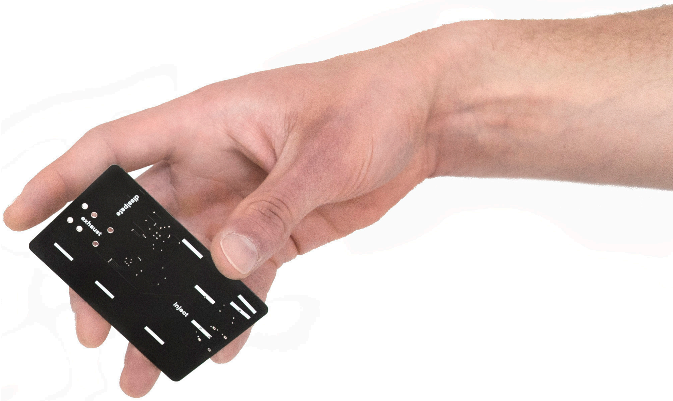
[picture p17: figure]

loading

finding

sending

Cloud

## rhizm use flow


## rhizm

What if blockchain could do something useful? What if we could contribute to the dilemma of social networks being an unsecure and boring space? We have invented rhizm - a physical smart card with high-end technology and cutting edge design inhaling the spirit of the future - free and decentralized.

## a new interaction

Rhizm creates a rhizomatic network, a social sandbox via an all new interaction called intercourse. Every card is unique due to its id in the rhizm blockchain. Meet partners, conduct intercourse and push it to the cloud. Once both partners have done that, the intercourse wil
be cryptographically verified.

## from bare metal to the cloud

At rhizomaticmachines.com you will find all verified intercourses creating a graph that visualizes the diversity and complexity of social interactions. Free your mind and play around with our public API creating your own experience with rhizm. Customize your rhizm and invent unforeseen applications to make the world a better place.

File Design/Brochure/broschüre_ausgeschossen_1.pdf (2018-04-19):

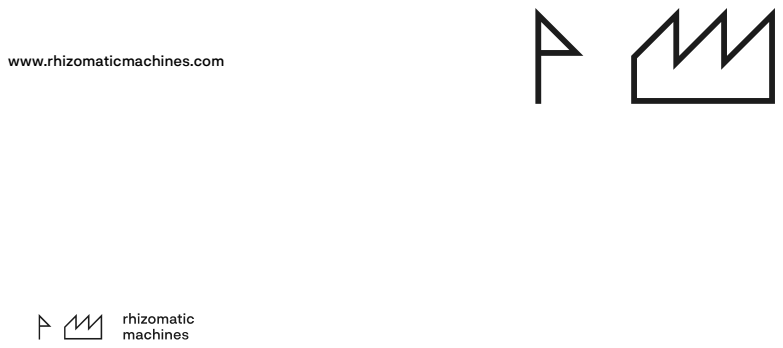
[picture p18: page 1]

www.rhizomaticmachines.com

## rhizm electronical layout

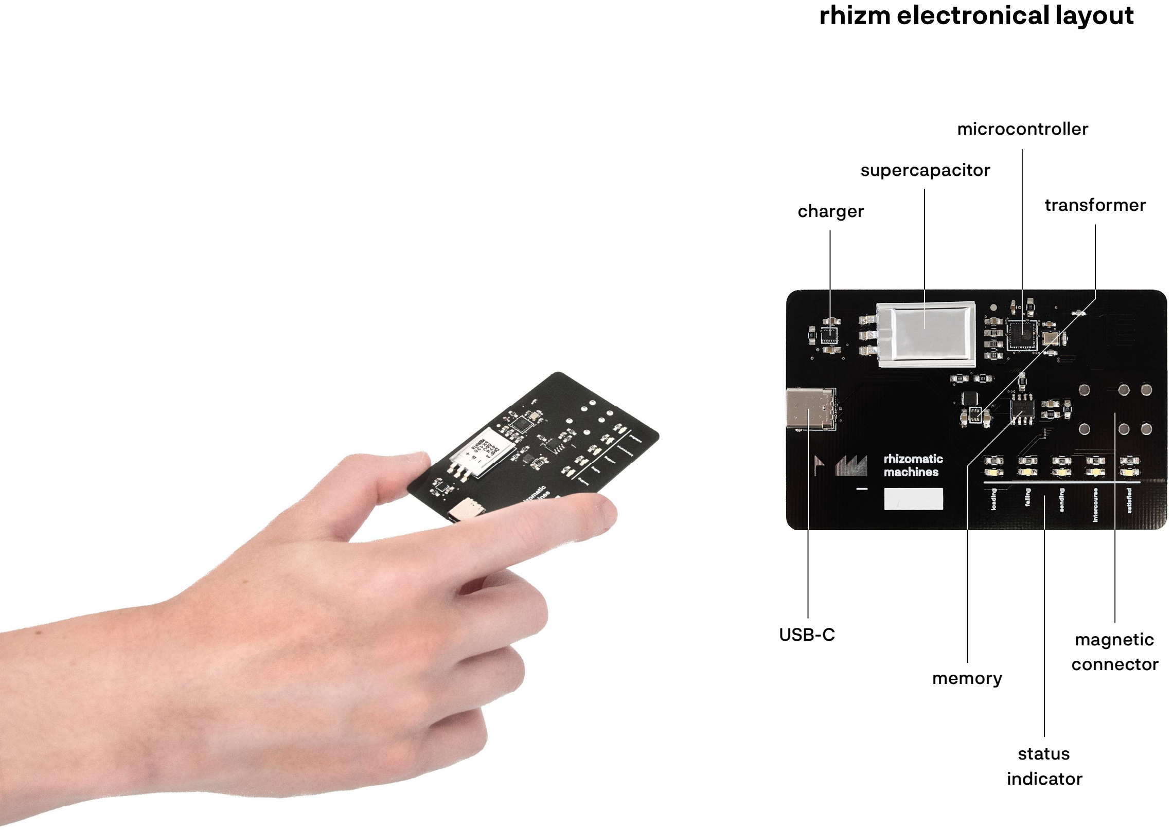
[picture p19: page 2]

supercapacitor

charger

USB-C | magnetic connector

status
indicator

memory

microcontroller

transformer

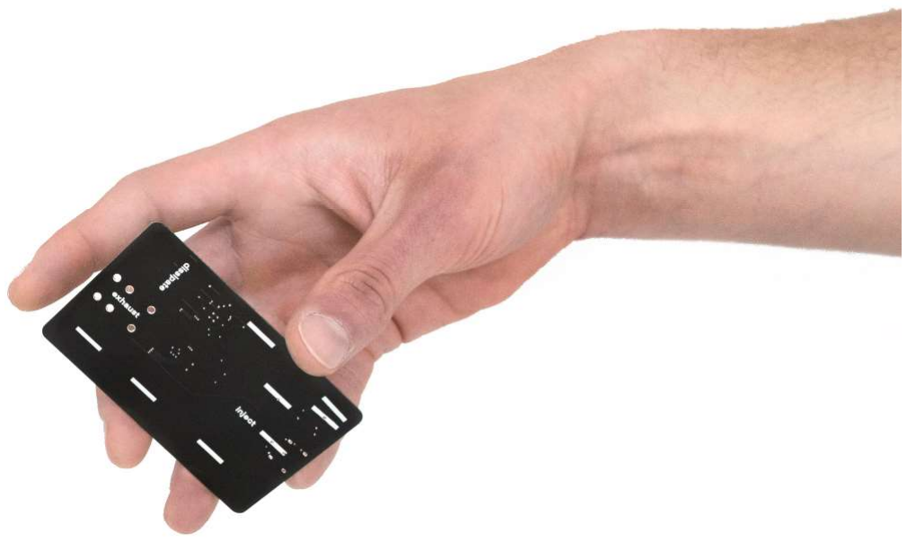
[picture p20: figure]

loading

finding

sending

Cloud

## rhizm use flow

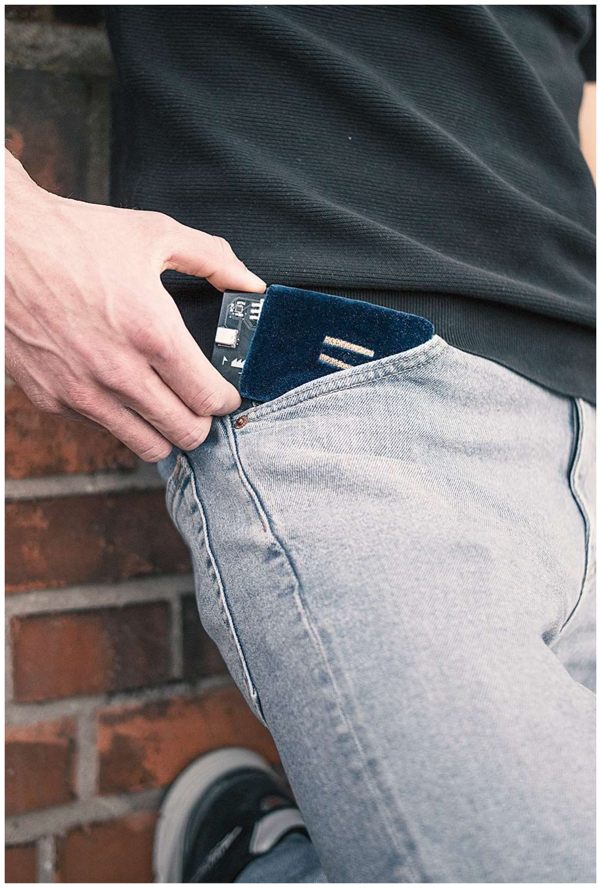
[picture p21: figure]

## rhizm

What if blockchain could do something useful? What if we could contribute to the dilemma of social networks being an unsecure and boring space? We have invented rhizm - a physical smart card with high-end technology and cutting edge design inhaling the spirit of the future - free and decentralized.

## a new interaction

Rhizm creates a rhizomatic network, a social sandbox via an all new interaction called intercourse. Every card is unique due to its id in the rhizm blockchain. Meet partners, conduct intercourse and push it to the cloud. Once both partners have done that, the intercourse wil
be cryptographically verified.

## from bare metal to the cloud

At rhizomaticmachines.com you will find all verified intercourses creating a graph that visualizes the diversity and complexity of social interactions. Free your mind and play around with our public API creating your own experience with rhizm. Customize your rhizm and invent unforeseen applications to make the world a better place.

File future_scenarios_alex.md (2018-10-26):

# Szenarien

* Siegelring
* Event based
* Colletable
* Mystische Crypto
* Social Network
* Einmalig ausführbare Aktion zwischen Peers
* System das mit Hilfe künstlicher Wertschöpfung Leute dazu auffordert sich miteinander zu treffen
* Karten zu kaufen wie Zigaretten, enthalten einen bestimmten Wert, den man zusamenn entladen kann, absoluter Kick --> reich gleich mehr Geld (Abstraktion der Zigarette), je mehr Geld, desto sichtbarer im Cluster
* Wert der Karte steigt, wenn sie nicht gepaart wird. Vorteile für Outsider?
* Meta-Game: Mesh aufspannen
* Authentifizierung

----

* Social Network

## Abstract Cigarette
Ein herausragendes Produkt des 20. Jahrhunderts war die Markenzigarette. Sie funktioniert auf Grund ihrer Wirkung in Kombination mit einer ausgeprägten Markentreue und sozialem Druck bzw. Anlässen. Das konzeptionelle Kondesat der Zigarette ist der Kick in Gesellschaft zu demonstrieren, dass man bereit ist einen Teil seines Wohlergehens aufzugeben. Wie kann man diesen Mechanismus in die Digitalisierung des frühen 21. Jahrhunders transportieren? Die Bereitschaft bei einer sozialen Interaktionen einen finanziellen Betrag zu vernichten. Die Karte wird am Kiosk als Markenprodukt verkauft, das sich an dem Zeitgeist von Millenials labt. Jede Karte hat, wie eine Packung Zigaretten, eine fixe Anzahl Interaktionen. Durch das Entladen kann der Nutzer seine soziale Dominanz beweisen. Premiumprodukte ziehen einen höheren Betrag pro Interaktion ab und entleeren Karten normaler Menschen schneller. Can't touch this.

## Social cluster presence
Eine Interaktion zwei Karten erzeugt einen Node in einem graph based social network. Das Netzwerk ist angelehnt an zeitgenössische Dienste wie Instagram oder Twitter und lässt sich genauso gut integrieren. Die Essenz ist aber kein linearer Feed, sondern ein Graph mit mehrdimensionalen Verkettungen und Clusterbildung aus sozialen Bindungen und Geolokalität. Mit jeder Interaktion verewigt man sich in dem Netzwerk unlöschbar und für alle sichtbar. Die Interaktion ist analog zum Schnitzen an Bäumen. Teurere Interaktionen erzeugen kräftigere Nodes. Jedem Node kann ein Text und/oder Foto angefügt werden, sodass es als Erinnerung dient. Die Website ist schlicht und einfach, aber prägnant.

## Real social network (Menschen begenen)
Mit dem Kauf einer Karten nimmt man einem Spiel teil, das die Spieler anreizt, sich zu begegnen. Eine AI schlägt auf Grund verschiedener Bedingungen Kontakte vor, deren Pairing zu Punkten führt. Es gibt lokale und globale Leaderboards sowie alternative Darstellungen mit Graphen etc. Der Reiz liegt bspw. daran, dass ich zwar mit jemandem aus Bremen zwei Punkte bekommen, in Hamburg sind es aber vielleicht fünf und in Kolumbien 200.

## Authentifizierung für Zirkel
Die Karte dient als Instrument zur Authentifizierung und Interaktion auf Events wie Festivals. Die Karten sind daran gebunden und sind danach unbrauchbar oder dienen als Artefakt. Jedoch lässt sich die Historie der Interaktionen online verfolgen und zwischen den IDs anonymisiert kommunizieren. So ist man bspw. auf Festivals nicht direkt darauf angewiesen seine Telefonnummer herzugeben. Gleichtzeitig wird allen anderen Nutzern das Verhalten transparent dargestellt, also mit wem man sich getroffen hat oder wie oft man sich Getränke geholt hat oder ob man einmal dem Headliner begegnet ist.

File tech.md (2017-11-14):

## Nitinol

* [Material Bearbeitung](https://confluentmedical.com/tech-center/nitinol-facts/)
* [Nitinol Lines](http://www.ebay.de/itm/Muscle-Wire-with-Ring-Terminal-Light-Stitches-Nitinol/301724584869)
* [Nitinol Form Shaping Instruction](http://www-personal.umich.edu/~btrease/share/SMA-Shape-Training-Tutorial.pdf)

## Mechanics

* [Pan-Tilt-Rotate-Einheiten](https://nodna.de/Pan-Tilt-Rotate-Einheiten)
* [Measuring photosynthesis](http://www.vision-systems.com/articles/2014/06/vision-system-measures-intensity-of-photosynthesis-in-plants.html)

## Machine Learning

* [One pixel attack for fooling deep neural networks](https://arxiv.org/pdf/1710.08864.pdf)

## Projects

* [Space Junk](http://www.dwbowen.com/spacejunk)
* [Telepresent Wind](http://www.dwbowen.com/telepresent-wind)
* [Black Flags](https://www.youtube.com/watch?v=6XVrrmm9jno)
* [Tree Time](http://brucecannon.org/projects/tree-time/)

## Tree tech

* [Oldest tree on earth](https://www.welt.de/wissenschaft/umwelt/article160310407/Das-ist-der-aelteste-Baum-der-Welt.html)
* [Arbre du Ténéré](https://de.wikipedia.org/wiki/Arbre_du_T%C3%A9n%C3%A9r%C3%A9)
* [List of notable trees](https://en.wikipedia.org/wiki/List_of_notable_trees)

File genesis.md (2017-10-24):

# Rhizomatic Sublime

Eine Wiese aus Elefantengras (miscanthus rhizomen) und maschinenhaften Agenten im Raum.
Windgeneratoren lassen das Gras im Raum bewegen.

Rauschen (http://www.youtube.com/watch?v=_D6Zi9OlUVM)
Wiesensound (http://www.youtube.com/watch?v=2F16FjGLiO0)
BambusImWind (http://www.youtube.com/watch?v=X_K-7AV-tl4)

Das Rauschen des Windes legt sich über die sich bewegenden Gräser.
Die Agenten versuchen die natürlichen Bewegung des Grases nachzuahmen.
Ihr Ziel ist es:

1. Die Bewegung des Schilfes zu imitieren um im Rauschen zu verschwinden. Mimikry.
2. andere Agenten zu identifizieren und ihr eigenes erlentes Bewegungsmuster zu übertragen.

genetische Evolution.

Rauschen akustischer Ebene und Rauschen der Grasbewegung auf visueller Ebene.
Synästhesie.
Verstärkung des Erhabenen.

## Why

Die Menschheit ist von AI befallen. In die DNA wurde von Millionen von Jahren der Fortschrittsgedanke
eingepflanzt mit dem Ziel Individuen und Organisationsformen zu entwickeln, damit wir diese exterrestrische künstliche Intelligenz reproduzieren können.

## Romantische Lyrik

Clemens Brentano
Liebesnacht im Haine 

Um uns her der Waldnacht heilig Rauschen 
Und der Büsche abendlich Gebet, 
Seh ich dich so lieblich bange lauschen 
Wenn der West durch dürre Blätter weht.

Clemens Brentano
Abendständchen 

Hör, es klagt die Flöte wieder,
und die kühlen Brunnen rauschen!
Golden weh'n die Töne nieder,
stille, stille, lass uns lauschen!

## Technik

* NiTiNol Wire

MuscleWire (http://www.youtube.com/watch?v=N188-MJZrzo)

* Gyroskopsensor MPU-6050
* 2 Achsen Motor Gimbal: http://www.ebay.de/itm/282284267943

 Gimbal (http://www.youtube.com/watch?v=7Q9bNwmFeeU)

* optische Echtzeitbewegungserkennung 

## Spielarten

* Pflanzenwachstum als Faktor

## Verwandte Arbeiten

* Kerstin Ergenzinger / Whiskers in Space (http://www.nodegree.de/works/whiskers/inspace-video.html)

* Shawn Decker - Prairie: https://vimeo.com/77759818

# Proposal in English

A meadow of elephant grass (miscanthus rhizomen) sways in airy currents.
Embedded in the green thicket imitations of grass try to hide their mechanical otherness.
They are tricky, mimicking their natural environment.
Lurking for their conspecifics, the agents are searching for patterns, for information that reveals exceptional artificiality in their surrounding.
Agents punish their rhizomaticly connected cohabitants for misbehavior, the ones diverging from the natural normal.
An artificial species tries to vanish in sensorial noise, leaving behind their machine-like corporeality, becoming sublime.

The noise of whispering leaves sets emerges from the moving meadow.
Agents try to mimic natural movement of grass.
Their aim:
1. Mimicry. Dissappear in Nature.
2. Identification. Eliminate Otherness.
3. Evolution. Spread knowledge to the rhizome.

Noise as a non-signal and noise a sound: synaesthesia.

Clemens Brentano
Liebesnacht im Haine 

Um uns her der Waldnacht heilig Rauschen 
Und der Büsche abendlich Gebet, 
Seh ich dich so lieblich bange lauschen 
Wenn der West durch dürre Blätter weht.

Elephant grass
Nitinol
Wind machine

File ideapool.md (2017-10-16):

## Pool

* Agentur für exklusive Unternehmensrepräsentation gründen: Die Agentur ist nicht zu buchen und bietet ihre Werke selbst ausgewählten Kunden an (Nachfrage durch Exklusivität). Kern der Arbeit ist das Portfolio und der Clientchart auf der Website. Salonmalerei 2.0, postfaktisch, spekulativ. Im Projekt werden mehrere Werke gezielt erarbeitet und echten Kunden angeboten. Die Agentur als Plattform für das rhizomatic sublime, die Unternehmenskultur gestützt auf künstlerische Auseinandersetzung. Manifeste statt Corporate Management. Make money great again.
* Galerie für digitale Kunst mit Smart Contracts programmieren: Die Galerie verwaltet sich selbst und agiert als Börse für den (finanz-spekulativen) Kunstmarkt. Kunstwerke können jederzeit durch eine höhere Ablösesumme dem Besitzer abgekauft werden (bspw. 120%, wobei 15% an den Besitzer gehen, 3% an die Galerie und 2% an den Künstler). Eventuell bekommen Besitzer eine Dividente von der Galerie ausgeschüttet. Einreichungen erfolgen über Smart Contracts, die Aufnahme in das ledger über eine erfolgreiche Kaufabwicklung. Die Kunstwerke sollten keine Materialität besitzen (Internet) oder allgemein zugänglich sein (öffentlicher Raum). Die Galerie existiert sowohl in der Blockchain als auch im Internet: Eine Web-*Galerie* sortiert nach den teuersten Kunstwerken.
* Plattform für Kunsthochschularbeiten: Eine Online-Galerie erschaffen, die den Mythos der kulturellen Elite "Kunsthochschule" ausnutzt, um Kunsthochschularbeiten aus kapitalistischer Motivation zu Kunst zu erklären.
* [Kunst oder Cash](https://github.com/maxwolfs/rhizomatic-sublime/blob/master/Kunst%20oder%20Cash.md): Gegenüberstellung zweier Kunstwerke, das schwächere wird zerstört, Cash oder Aura. Derivate?
* reaktionsgleichung mit variablen. viele kleine maschinen.
mimikri um im natürlichen rauschen als akteur zu verschwinden.
machine learning kann nichts mit rauschen anfangen. und verschwindet in der wahrnehmbarkeit ihrer mitmaschinen.
das medium? irgendwas was man gut beobachten kann in der ausstellungssituation.
zb. wiese : windgenerator -> grashalme / eingebettet artifical grashalme die versuchen durch nachahmung ihrer umgebung zu verschwinden
aber versuchen andere ihrer art aufzuspüren und damit stillegen oder dadurch exakt ihre eigene bewegung synchron übernehmen. genetische evolution.

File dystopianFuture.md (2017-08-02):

With Elon Musk and Mark Zuckerbergs current discussion about up- and downsides of AI developement,
question arise where everyday life leads in the next decades. In 1987 there weren't mobile phones,
the GSM has just been formalized by the European Comunity. 30 years later nearly everyone in the 
world has a smartphone, being connected to the world wide web. The calculation power has exploded
as the storage and memory space. The data being created has reached levels no one can even handle.

In the Industrial Revolution, better results were achieved by applying knowledge to
machines. In the productivity revolution, it was the application of knowledge to work. 
In the management revolution, the application of knowledge to the knowledge is based on systematic innovation, 
which can still increase productivity. 

Imagine a future where almost every aspect of our life is transferred to digitality by parameterizing everything.
Everyday life will then be calculated. Analog life will vanish. No nature, only culture. Here the most advanced
software-hardware combination will perform best in the internet of everything. Every human will have its own AI 
automatizing task from finances, decision what to read, like, consume, etc. This also means a gigantic increase of traffic
which will lead most probably into the loss of net neutrality. 

With every platform and service, private and public, parameterizing their little bubbles and creating APIs for their data 
exchanging working as Hubs; basically we are building a world/database not for us humas but for algorithms.
In 10years every single area in our life is digitalized, it might not be possible anymore to do public/legal actions 
the 'analog' way in a human interactable way.

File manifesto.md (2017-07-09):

## Becoming of a Manifesto

Stefan Germer beschreibt die Salonmalerei im 19. Jahrhundert als Malerei zum Zwecke der Repräsentation
ihrer Auftraggeber, zu dieser Zeit oftmals Adelige. Funktion? Öffentlichkeit? Spektakel?

Heutzutage werden Arbeiten wie beispielsweise von onformative, WhiteVoid von Unternehmen für deren Repräsentation
in Auftrag gegeben oder genutzt. Künstler bleiben in ihrer Funktion des Gauklers zur Unterhaltung oder Bespielung
der Macht. Dies geht sogar soweit, dass bei der absoluten massenhafen Rezeptionsmöglichkeit digitaler Medien
Unternehmen zu den größten und einflussreichsten der Welt werden, die ihr Geld damit verdienen eine globale
überall und jederzeit verfügbare Bühne bereitzustellen.

Aura. Die Unnahbare Ferne. Was damals noch keine Kunst war, wie beispielsweise die Medusa von Gericault,
wird erst duch die zeitliche Verschleierung des Vergessens zur Kunst in einem Prozess der der Überlagerung der
Raumresonanz von Alvin Luciers 'I am Sitting in a Room' gleicht. Die Aura ensteht, der Ausgangspunkt ist in
unnahbare Ferne gerückt, ungreifbar. Nur noch Nebel.

Kunst wird also nur dann zu ihresglechen, wenn sich der Schleier des Unscharfen über das Ursprüngliche gelegt hat
und den Raum für unendliche viele Mythen die blind versuchen blind nach der Referenz zu greifen und sie immer mehr
verfehlen werden. Dieser immer größere Abstand zum Ursprünglichen wird nach einer gewissen Zeit zum Selbstzweck
und der Kern der Sache immer nebensächlicher, zu einem unendlich kleinen Nachhall, oder eben der von
Walter Benjamin beschriebenen Aura.

Nicht umsonst wird im Digitalen der Ruf nach dem Recht auf Vergessen sogar aus der Politik laut. Was ist wenn
die Vernetzung von Abermilliarden Transistoren nur einen Stream speisen, einen gigantischen Fluss aus kurz aufblitzenden
Daten bilden, ehe sich das Delta im Meer der Irrelevanz verlieren?
4 
Ähnlich auch das aktuelle als Postfakisch bezeichnete Phänomen, was eigentlich nur die Tatsache beschreibt,
dass die gesamte digitale Abbildung nur eine Annähungung, ein Mythos der gesamten analog materialisierten Welt darstellt.
Das Internet, also das gesamte Netzwerk an Endgeräten von Laptops, Fernsehern, Smartphones und so weiter an denen wir
tagein- tagaus immer mehr in einem Prozess des transhumanen zu neuen Lebensformen übergehen, sind für uns nicht nur
schwarze Spiegel, sondern vielmehr Tore zu den vernebelten Wolken des ästhetisch Erfahrbaren. Ein Rausch mit unendlich
erscheinenden Decay.

## Bemerkungen und Beobachtungen

* Der Einstieg in die Arbeit muss jederzeit funktionieren, den Rezipienten verführen.
* Popkultur ist im Vergleich zu Kunst im stärkeren Maße von der Auratisierung beflügelt, siehe Diskurs von Popmusik (90er sind in, 80er verschwinden im Schleier, von den 70ern ist nur noch ominöse Hippie-Energie geblieben)
* Inwiefern interargieren das Kunst- und das Popkultur-Dispositiv und wie verschieben sie sich die Denksysteme zueinander, um dieses Kontinuum der Verschleierung zu bewirken? Ist die Schaffung der Aura ein Produkt der Konstitution der beiden oder ein Relikt der topischen Verschiebung, also eine archäologische Betrachtung der kulturellen Moräne?
* Kann es so etwas wie speukulative Kunst geben, die Diskurs über die Entwicklung der Unternehmensrepräsentation schafft (Kunstsammlungen großer Bankhäuser bspw)? Ähnlich Wellness-Kunst. Ist das Spekulation oder Selbst-Reflektion?

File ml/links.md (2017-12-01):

* [Brief History of Neural Nets and Deep Learning](http://www.andreykurenkov.com/writing/a-brief-history-of-neural-nets-and-deep-learning/)
* [3D Visualiations of Neural Nets](https://www.youtube.com/watch?v=3JQ3hYko51Y)
* [mouse brain 3d brain visualiation](https://www.youtube.com/watch?v=vbLtLYkW6hI)
* [fiberglass installation artist](http://carlobernardini.carlobernardini.it/eng/)
* [visual introduction to machine learning](http://www.r2d3.us/visuelle-einfuehrung-ins-maschinelle-lernen-teil-1/)
* [wind sensor work](https://vimeo.com/41744045)
* [interaction i installation](http://www.rlfbckr.org/work/interface-i/)

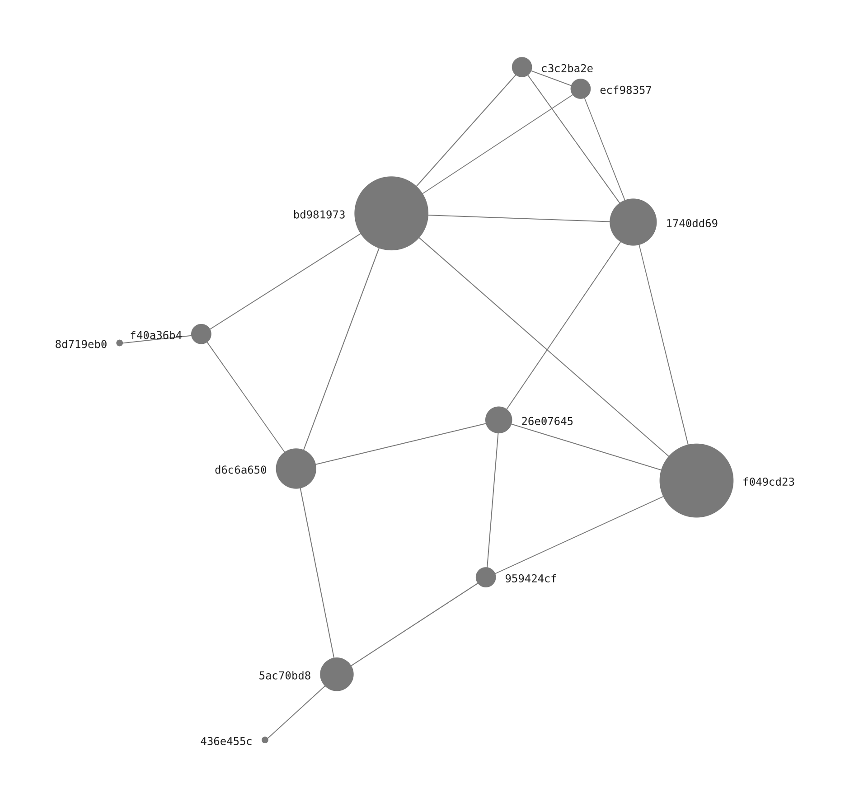
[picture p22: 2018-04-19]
Design/Brochure/images/graph.png

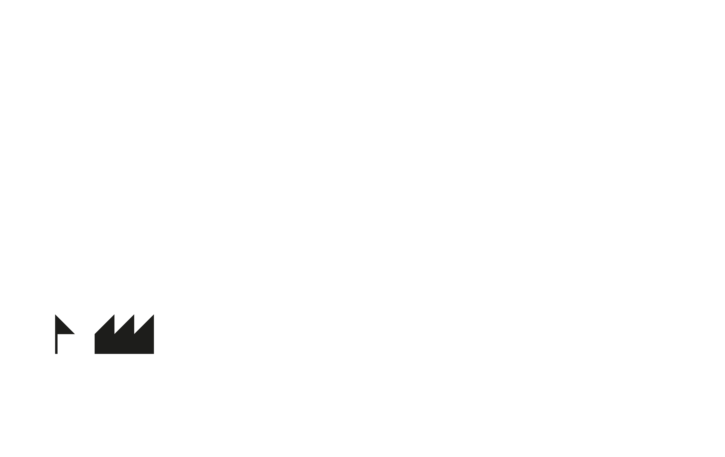
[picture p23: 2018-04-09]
Design/Graphics/rhizm_layout_1_footprint_eco-front-01.png

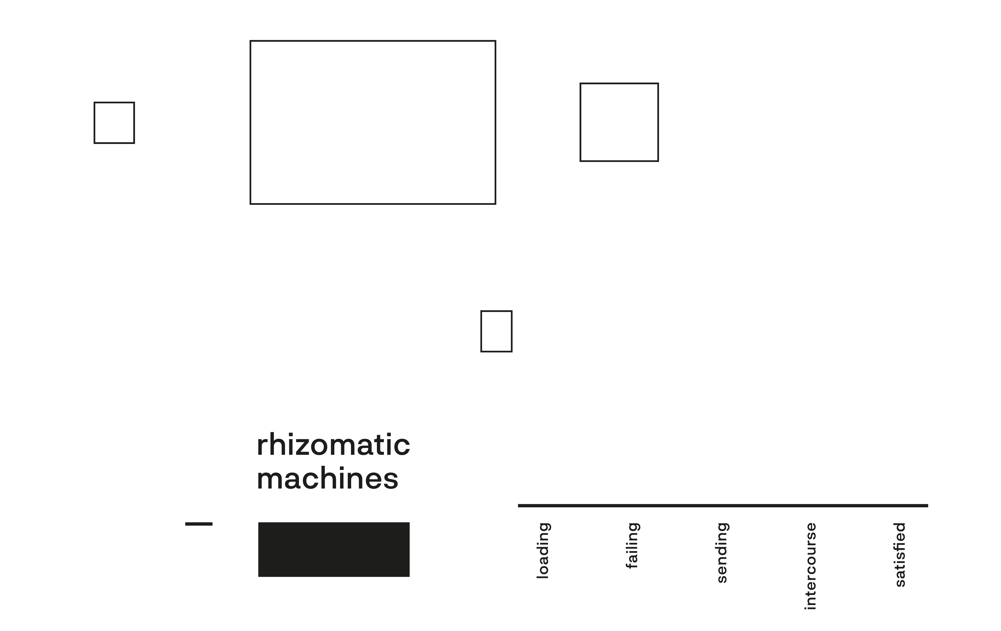
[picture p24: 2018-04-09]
Design/Graphics/rhizm_layout_1_footprint_silk-front-01.png

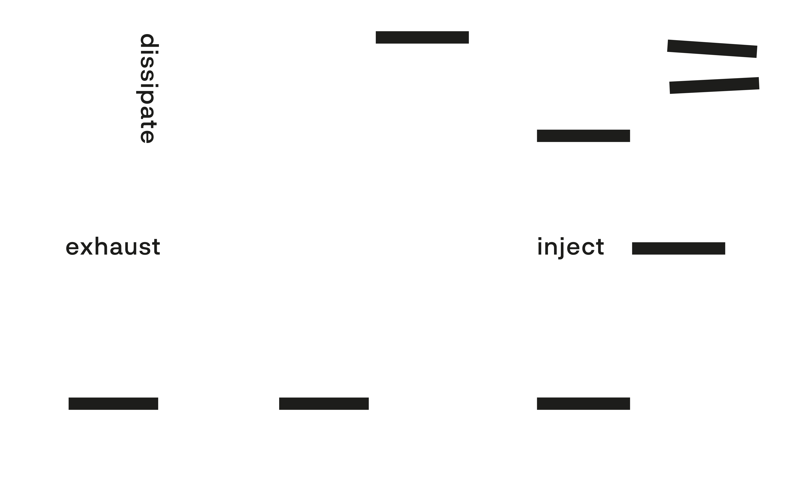
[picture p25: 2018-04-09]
Design/Graphics/rhizm_layout_1_footprint_silk-back-01.png

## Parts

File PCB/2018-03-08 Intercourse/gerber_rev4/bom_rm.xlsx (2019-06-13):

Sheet: Sheet1
 |  |  | xxxx xxxx xxxxx xxPCS BOM (Sample Bill of Materials)
Item # | *Ref Des | *Qty | Manufacturer | *Mfg Part # | Description / Value | *Package | Type | Your Instructions / Notes
1 | C2, C4, C11, C8 | 4 | Murata | GRM21BR61C106KE15L | Multilayer Ceramic Capacitors MLCC - SMD/SMT 0805 10uF 16volts X5R 10% | 0805 | SMD
2 | C3 | 1 | Murata | GCM21BR71H105KA03L | Multilayer Ceramic Capacitors MLCC - SMD/SMT 0805 1uF 50volts X7R 10% | 0805 | SMD
3 | C5 | 1 | TDK | CGA4J3X7R1C225K125AB | Multilayer Ceramic Capacitors MLCC - SMD/SMT CGA 0805 16V 2.2uF X7R 10% AEC-Q200 | 0805 | SMD
4 | C7, C6 | 2 | Murata | GCM1885C2A100FA6D | Multilayer Ceramic Capacitors MLCC - SMD/SMT 0603 10pF 100volts C0G 1% | 0603 | SMD
5 | C9 | 1 | Murata | GCM188R71C105KA64D | Multilayer Ceramic Capacitors MLCC - SMD/SMT 0603 1.0uF 16volts X7R 10% | 0603 | SMD
6 | C10 | 1 | Vishay | VJ0603A5R6BXJPW1BC | Multilayer Ceramic Capacitors MLCC - SMD/SMT 0603 5.6pF 16volts C0G +/-0.1pF | 0603 | SMD
7 | C12 | 1 | Murata | GCM188R91E104KA37D | Multilayer Ceramic Capacitors MLCC - SMD/SMT 0603 0.1uF 25volts X8R 10% | 0603 | SMD
8 | D5, D4, D3, D2, D1 | 5 | Lite-On | LTW-220DS5 | Standard LEDs - SMD White SMD LED 45.0-112.0mcd@ 5mA | 0805 | SMD
9 | J1 | 1 | Amphenol | 12401610E4-2A | USB Connectors USB TYPE C RCPT R/A SMT TOP MOUNT |  | SMD
10 | L1 | 1 | Murata | LQH3NPN4R7MJRL | Fixed Inductors 1212 4.7uH 1280mA 105C Tol=+/-30% | 1212 | SMD
11 | R1, R6 | 2 | Vishay | CRCW080512K0FKEA | Thick Film Resistors - SMD 1/8watt 12Kohms 1% 100ppm | 0805 | SMD
12 | R2 | 1 | Panasonic | ERJ-6GEYJ183V | Thick Film Resistors - SMD 0805 18Kohms 5% AEC-Q200 | 0805 | SMD
13 | R3 | 1 | Vishay | CRCW080533K0JNEA | Thick Film Resistors - SMD 1/8watt 33Kohms 5% | 0805 | SMD
14 | R5, R4 | 2 | Yageo | RT0805FRE0710KL | Thin Film Resistors - SMD 1/8W 10K ohm 1% 50ppm | 0805 | SMD
15 | R7 | 1 | Vishay | CRCW0805200RFKEA | Thick Film Resistors - SMD 1/8watt 200ohms 1% 100ppm | 0805 | SMD
16 | R12, R11, R10, R9, R8 | 5 | Vishay | CRCW0805220RFKEAC | Thick Film Resistors - SMD 1/8Watt 220ohms 1% Commercial Use | 0805 | SMD
17 | R13, R14, R15 | 3 | Susumu | RR1220P-102-D | Thin Film Resistors - SMD 1/10W 1Kohm 0.5% 25ppm | 0805 | SMD
18 | U1 | 1 | Analog Devices Inc. | LTC3225EDDB#TRMPBF | Power Management Specialised - PMIC 150mA Supercapacitor Charger | DFN | SMD
19 | U2 | 1 | Texas Instruments | TPS61221DCKR | Switching Voltage Regulators Tiny Low Inp Vltg Boost Cnvrtr | SC70 | SMD
20 | U3 | 1 | Adesto Technologies | AT25SF041-SSHD-B | NOR Flash 4Mb, 2.5-3.6V,104Mhz Serial Flash | SOIC | SMD
21 | U4 | 1 | Espressif | ESP8266EX | RF System on a Chip - SoC SMD IC ESP8266EX, QFN32-pin, 5*5mm | QFN32 | SMD
22 | Y1 | 1 | Abracon | ABM8W-26.0000MHZ-4-B1U-T3 | Crystals 26MHz 4pF -20C +70C10ppm | 3.2 mm x 2.5 mm | SMD
 |  | 38
Click for Instructions on How to Create a BOM (https://www.pcbway.com/blog/PCB_Assembly/How_to_Build_a_BOM__Bill_Of_Materials_.html)

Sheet: 2018-03-08 Intercourse 01
Source: | /Users/mwolfs/dev/rhizomatic-sublime/PCB/2018-03-08 Intercourse/2018-03-08 Intercourse 01.sch
Date: | 2019 May 27, Monday 12:18:52
Tool: | Eeschema (5.1.2-1)-1
Generator: | /private/var/folders/7n/kqz_8qv124v8cr469zvjl1bw0000gp/T/AppTranslocation/C6E06080-FB91-4960-B96D-37830AD4FA9C/d/kicad.app/Contents/SharedSupport/plugins/bom_csv_grouped_by_value_with_fp.py
Component Count: | 49
Ref | Qnty | Value | Cmp name | Footprint | Description | Vendor
AE1, | 1 | Antenna_Dipole | Antenna_Dipole | MyAntennas:AN91445_47_mils | Dipole antenna
C1, | 1 | DMF3 | DMF3 | Murata_DMF3Z:Murata_DMF3Z
C2, C4, C11, C8, | 4 | 10μF | C_Small | Capacitors_SMD:C_0805_HandSoldering
C3, | 1 | 1μF | C_Small | Capacitors_SMD:C_0805_HandSoldering
C5, | 1 | 2.2μF | C_Small | Capacitors_SMD:C_0805_HandSoldering
C7, C6, | 2 | 10pF | C_Small | Capacitors_SMD:C_0603_HandSoldering
C9, | 1 | 1μF | C_Small | Capacitors_SMD:C_0603_HandSoldering
C10, | 1 | 5.6pF | C_Small | Capacitors_SMD:C_0603_HandSoldering
C12, | 1 | 0.1μF | C_Small | Capacitors_SMD:C_0603_HandSoldering
C14, C13, | 2 | ? | C_Small | Capacitor_SMD:C_0603_1608Metric_Pad1.05x0.95mm_HandSolder | Unpolarized capacitor, small symbol
D5, D4, D3, D2, D1, | 5 | LED | LED | LEDs:LED_0805_HandSoldering
J1, | 1 | USB_C_Receptacle | USB_C_Receptacle | Connectors_USB:USB_C_Receptacle_Amphenol_12401610E4-2A
J2, | 1 | TP_RST | TEST_1P | C_Connectors:C_Connector_2mm
J3, | 1 | TP_TX | TEST_1P | C_Connectors:C_Connector_2mm
J4, | 1 | TP_RX | TEST_1P | C_Connectors:C_Connector_2mm
J5, | 1 | TP_GPIO0 | TEST_1P | Measurement_Points:Measurement_Point_Round-SMD-Pad_Small
J6, | 1 | TP_GND1 | TEST_1P | C_Connectors:C_Connector_2mm
J7, | 1 | TP_GND2 | TEST_1P | C_Connectors:C_Connector_2mm
J8, | 1 | TP_GND3 | TEST_1P | C_Connectors:C_Connector_2mm
L1, | 1 | 4.7μH | L | C_Connectors:LQH3NPN4R7MJRL
R1, R6, | 2 | 12K | R | Resistors_SMD:R_0805_HandSoldering
R2, | 1 | 17K | R | Resistors_SMD:R_0805_HandSoldering
R3, | 1 | 33K | R | Resistors_SMD:R_0805_HandSoldering
R5, R4, | 2 | 10K | R | Resistors_SMD:R_0805_HandSoldering
R7, | 1 | 200 | R | Resistors_SMD:R_0805_HandSoldering
R12, R11, R10, R9, R8, | 5 | ? | R_Small | Resistors_SMD:R_0805_HandSoldering
R13, R14, R15, | 3 | 1000 | R | Resistors_SMD:R_0805_HandSoldering
U1, | 1 | LTC3225 | LTC3225 | Housings_DFN_QFN:DFN-10-1EP_2x3mm_Pitch0.5mm
U2, | 1 | TPS61221DCKR | TPS61221DCKR | sc_70-6:sc_70-6
U3, | 1 | W25Q32FVSSIG | W25Q32FVSSIG | Housings_SOIC:SOIC-8_3.9x4.9mm_Pitch1.27mm
U4, | 1 | ESP8266EX | ESP8266EX | Housings_DFN_QFN:QFN-32-1EP_5x5mm_Pitch0.5mm
Y1, | 1 | 26 MHz | Crystal_GND24_Small | Crystals:Crystal_SMD_Abracon_ABM8G-4pin_3.2x2.5mm

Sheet: PCBWAY Template
 |  |  | xxxx xxxx xxxxx xxPCS BOM (Sample Bill of Materials)
Item # | *Ref Des | *Qty | Manufacturer | *Mfg Part # | Description / Value | *Package | Type | Your Instructions / Notes
1 | U1 | 1 | Linear | LTC3780EG#PBF | IC BUCK-BOOST CONV 24-SSOP | 24-SSOP | SMD
2 | U2,U4 | 2 | Fairchild | LM2904M | IC OPAMP DUAL -40-85 C 8-SOIC | 8-SOIC | DNS
3 | U3 | 1 | ON | LM317MBDTG | LM317M IC REG VOLT ADJ 500MA DPAK | DPAK | SMD
4 | U5 | 1 | Microchip | PIC16F690-I/SS | IC PIC MCU FLASH 4KX14 20SSOP | 20SSOP | SMD
5 | Q1 | 1 | Diodes Inc | GBJ10005-F | RECT BRIDGE GPP 50V 10A GBJ | GBJ | SMD
6 | R14,R18 | 2 | Panasonic | ERJ-6ENF4701V | RES 4.70K OHM 1/8W 1% 0805 SMD | 0805 | SMD
7 | R15 | 1 | Susumu | RL3720WT-R022-F | RES .022 OHM 1W 1% 0815 SMD | 0815 | SMD
8 | R16, R31 | 2 | Panasonic | ERJ-6ENF4702V | RES 47.0K OHM 1/8W 1% 0805 SMD | 0805 | SMD
9 | C5 | 1 | Murata | GRM21BR71C225KA12L | CAP CER 2.2UF 16V X7R 0805 | 0805 | SMD
10 | C7 | 1 | Murata | GRM21BR71C475KA73L | CAP CER 4.7UF 16V X7R 0805 | 0805 | DNS
11 | C8,C22 | 2 | Muruta | GRM21BR71C105KA01L | CAP CER 1.0UF 16V 10% X7R 0805 | 0805 | SMD
12 | CN6 | 1 | Molex | 538-53398-0671 | 1.25mm Connectors VERTICAL HDR SMT 6P | SMT 6P | SMD
13 | L1,L2 | 2 | Coiltronics | DR127-150-R | INDUCTOR SHIELD PWR 15UH SMD | SMD | SMD
14 | L3 | 1 | TDK | ACM1211-102-2PL-TL | CHOKE COMM MODE 1000 OHM 6A SM | SMD | SMD
15 | CN3,CN4 | 2 | Molex | 53047-0510 | CONN HEADER 5POS 1.25MM VERT TIN | 5POS | thru-hole
Click for Instructions on How to Create a BOM (https://www.pcbway.com/blog/PCB_Assembly/How_to_Build_a_BOM__Bill_Of_Materials_.html)

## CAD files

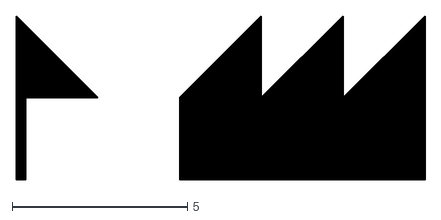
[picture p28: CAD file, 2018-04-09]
Design/Graphics/rhizm_layout_1_footprint_logo-front.dxf
11.7 x 4.67

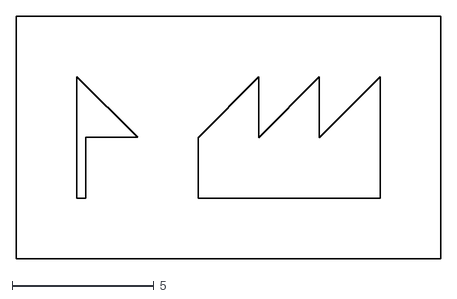
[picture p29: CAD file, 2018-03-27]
PCB/2018-03-08 Intercourse/shapes/logo_01.dxf
15.0 x 8.56

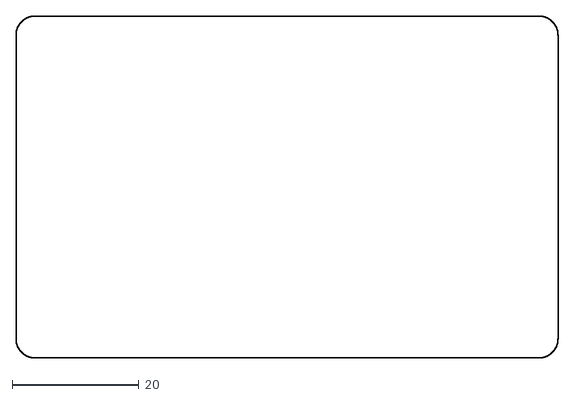
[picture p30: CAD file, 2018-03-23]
PCB/2018-03-08 Intercourse/shapes/cc.dxf
85.6 x 54.0

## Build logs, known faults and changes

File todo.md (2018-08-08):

## to Do

[] Szenarien bis 10.8
[] Website anpassen
[] Tech klären

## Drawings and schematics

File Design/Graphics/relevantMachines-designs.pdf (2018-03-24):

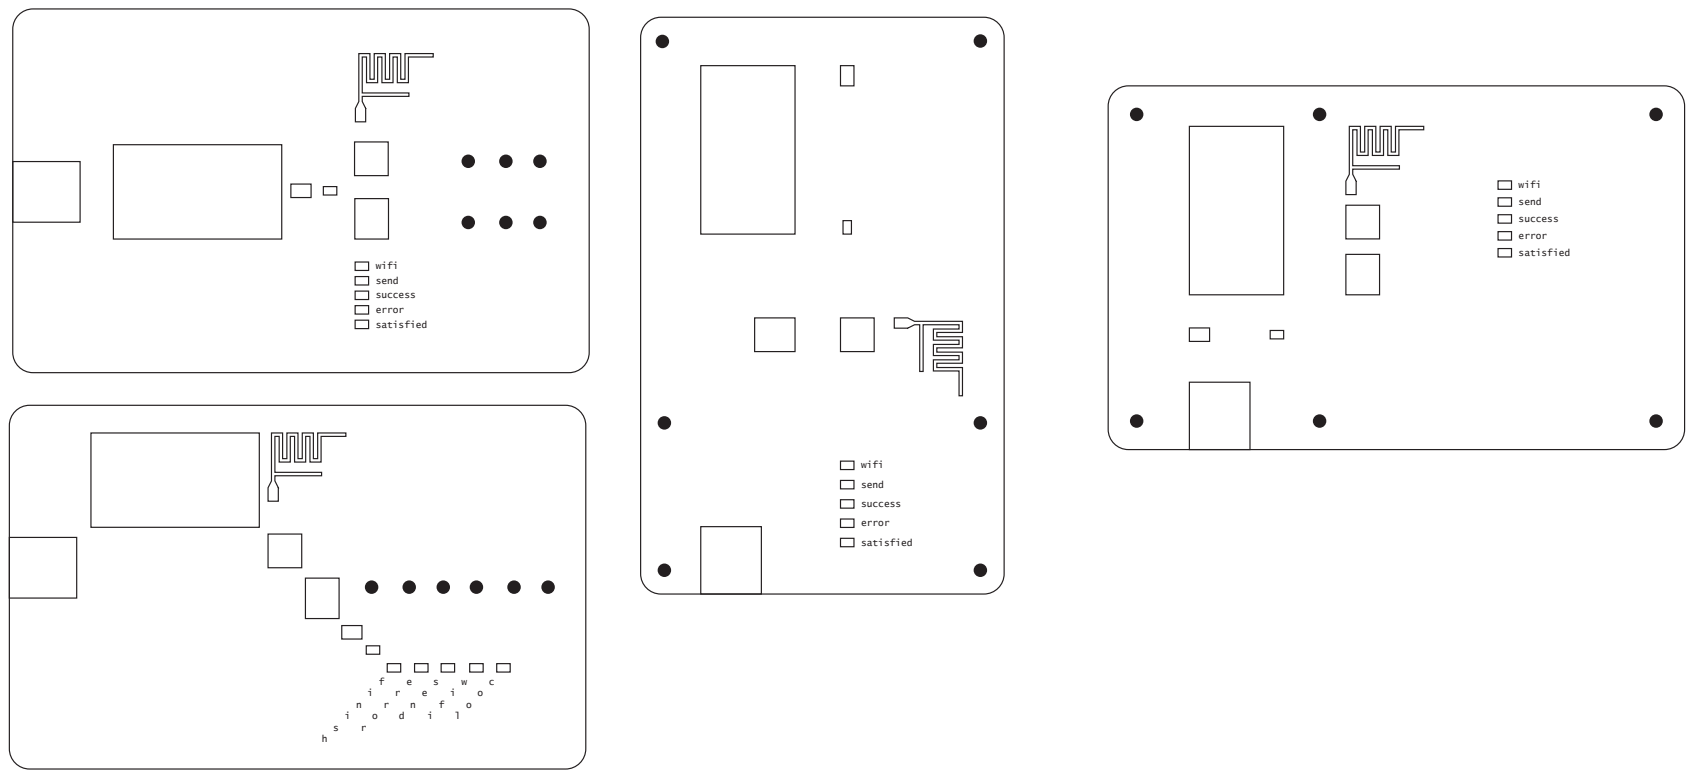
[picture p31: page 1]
send; error; wifi; success satisfied f; success; satisfied

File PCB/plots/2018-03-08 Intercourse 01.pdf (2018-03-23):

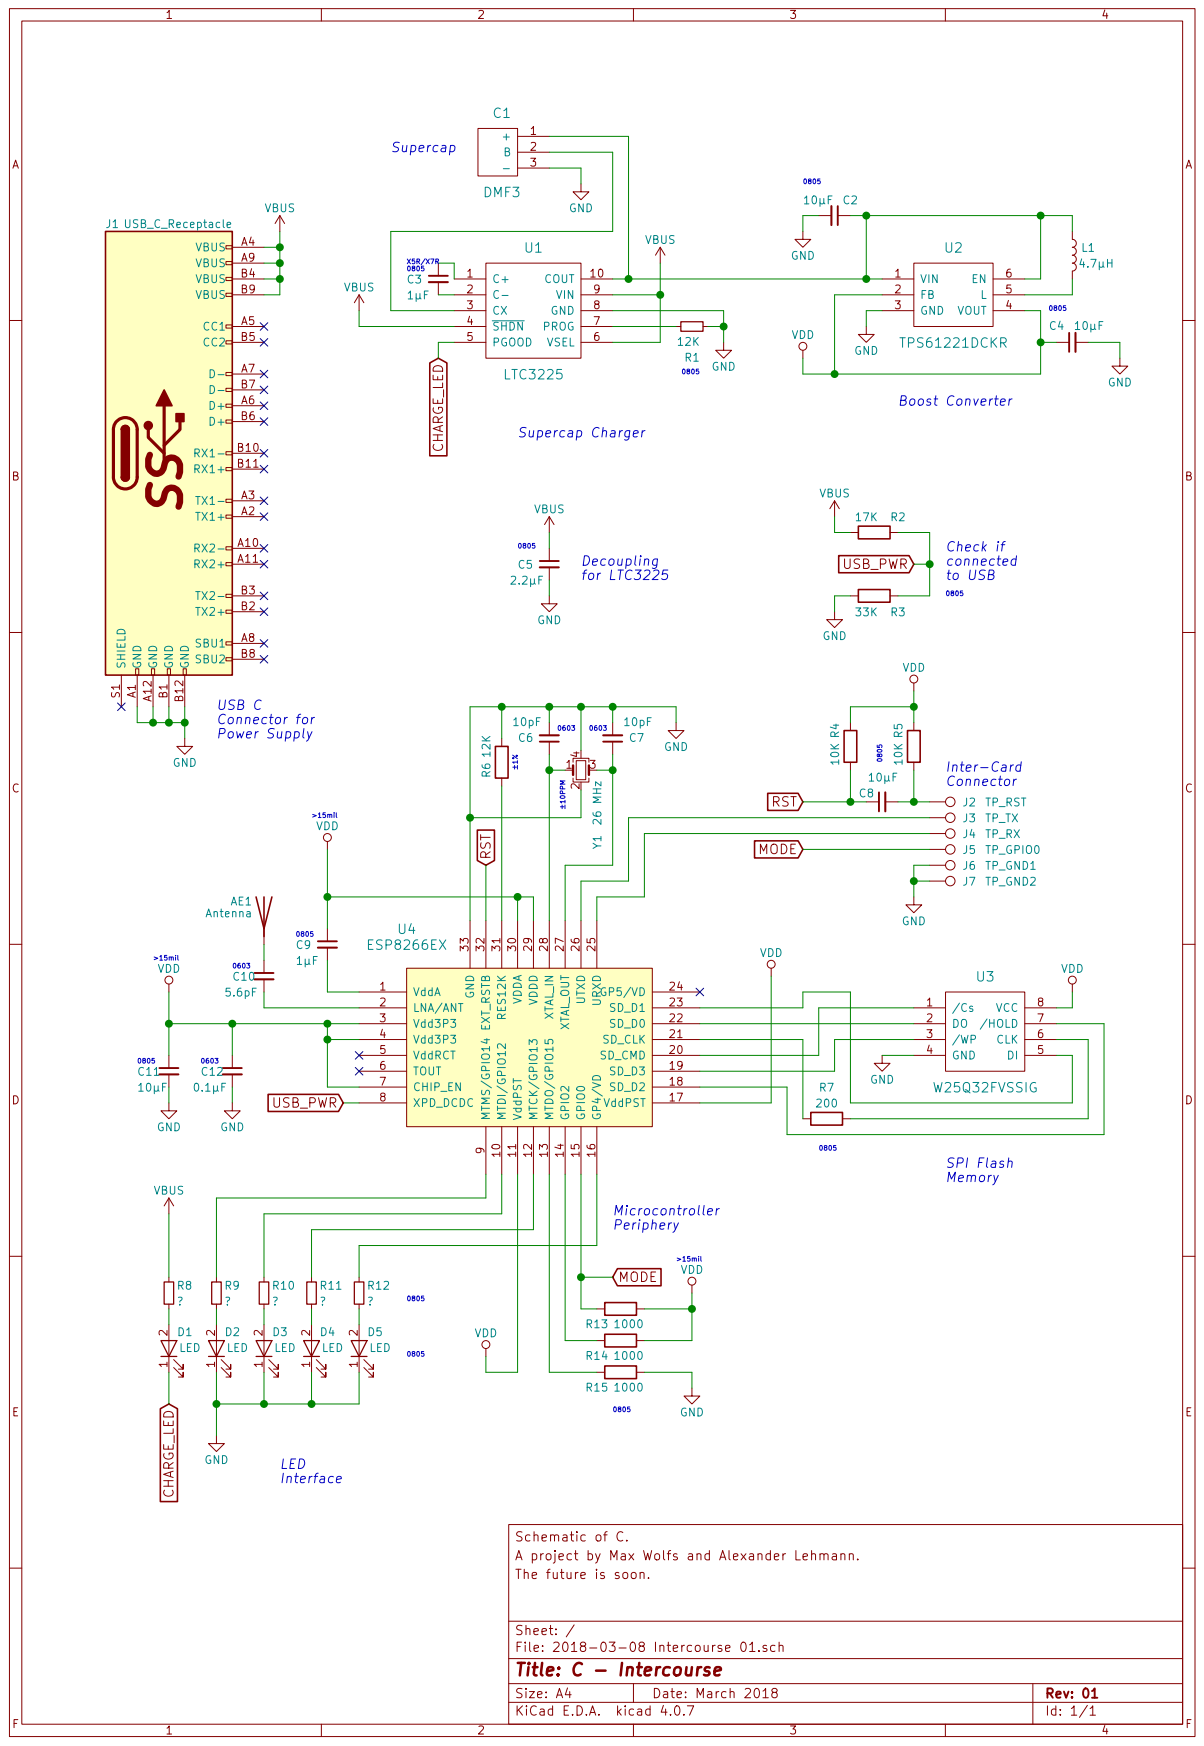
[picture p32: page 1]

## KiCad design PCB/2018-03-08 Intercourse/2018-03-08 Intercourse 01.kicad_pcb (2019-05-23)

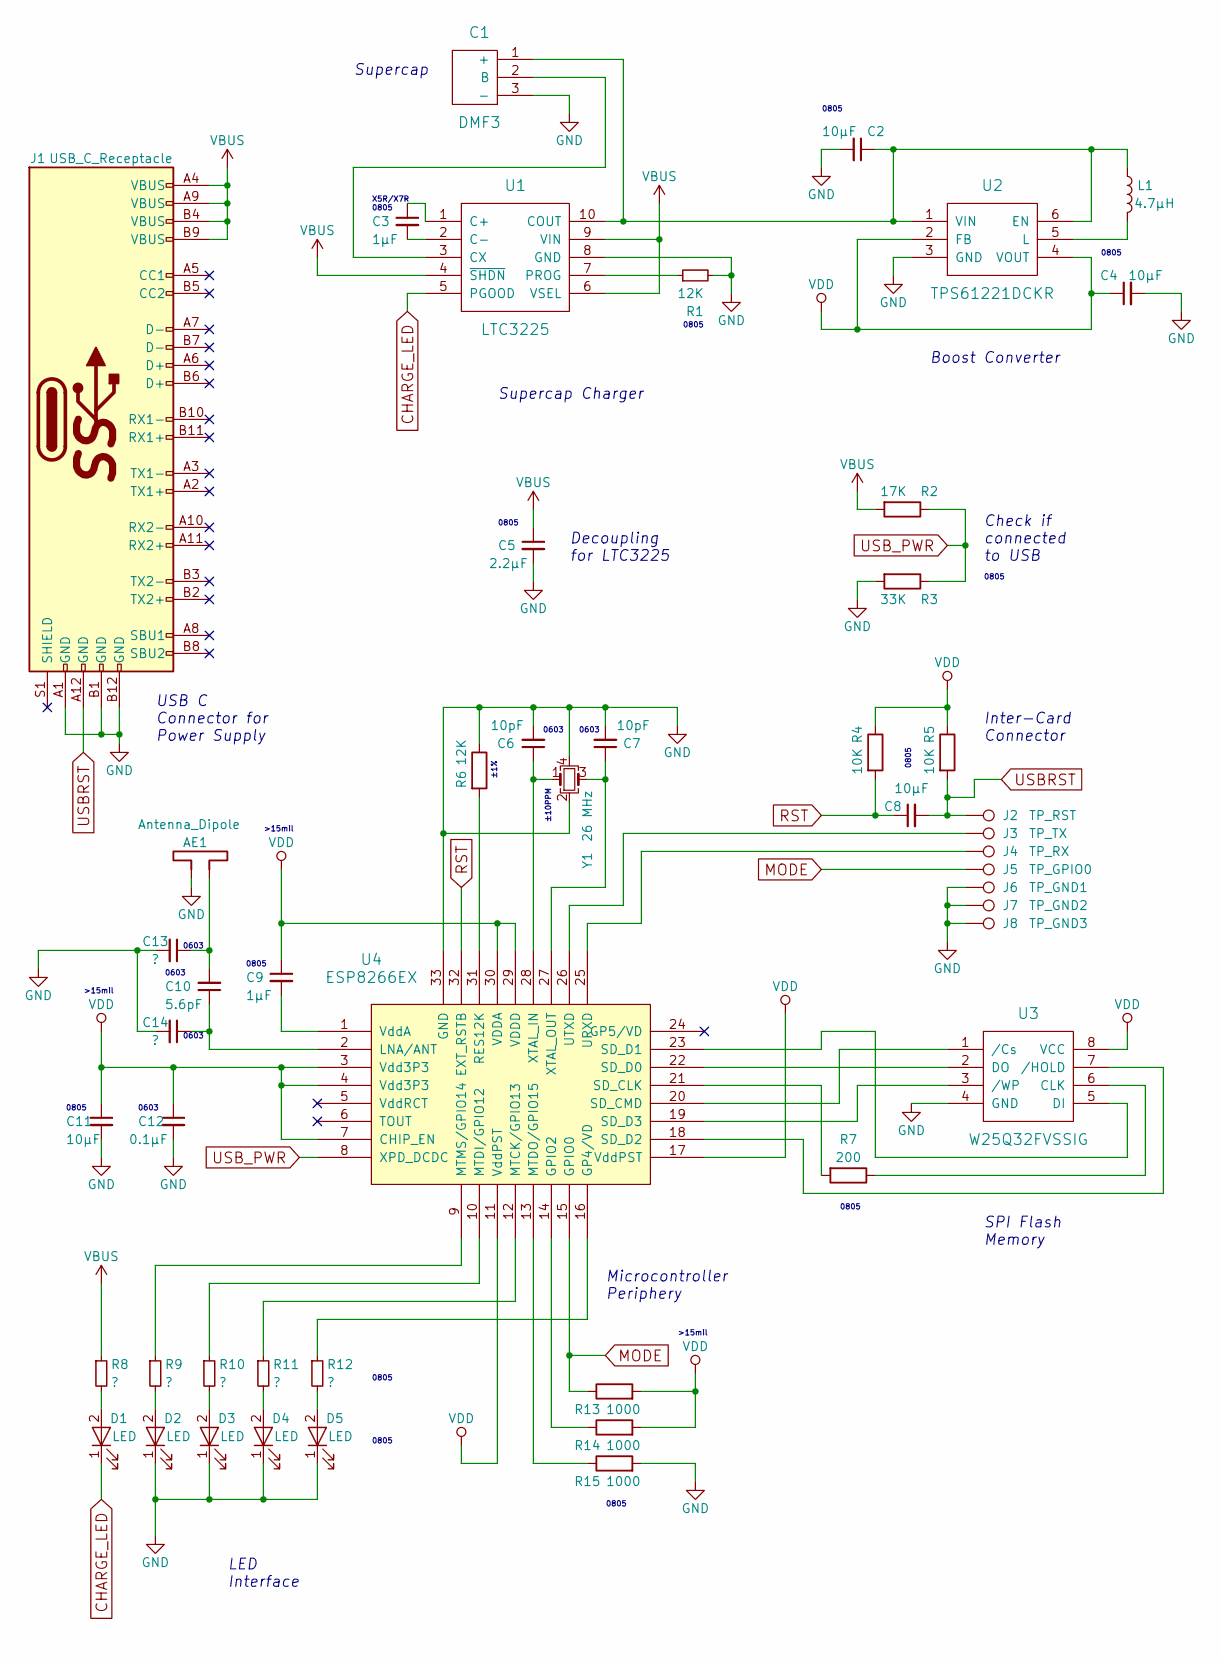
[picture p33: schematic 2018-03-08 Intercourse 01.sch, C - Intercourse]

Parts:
AE1: Antenna_Dipole; AN91445_47_mils
C1: DMF3; Murata_DMF3Z
C2, C4, C8, C11: 10μF; C_0805_HandSoldering
C3: 1μF; C_0805_HandSoldering
C5: 2.2μF; C_0805_HandSoldering
C6, C7: 10pF; C_0603_HandSoldering
C9: 1μF; C_0603_HandSoldering
C10: 5.6pF; C_0603_HandSoldering
C12: 0.1μF; C_0603_HandSoldering
C13, C14: ?; C_0603_1608Metric_Pad1.05x0.95mm_HandSolder
D1, D2, D3, D4, D5: LED; LED_0805_HandSoldering
J1: USB_C_Receptacle; USB_C_Receptacle_Amphenol_12401610E4-2A
J2: TP_RST; C_Connector_2mm
J3: TP_TX; C_Connector_2mm
J4: TP_RX; C_Connector_2mm
J5: TP_GPIO0; Measurement_Point_Round-SMD-Pad_Small
J6: TP_GND1; C_Connector_2mm
J7: TP_GND2; C_Connector_2mm
J8: TP_GND3; C_Connector_2mm
L1: 4.7μH; LQH3NPN4R7MJRL
R1, R6: 12K; R_0805_HandSoldering
R2: 17K; R_0805_HandSoldering
R3: 33K; R_0805_HandSoldering
R4, R5: 10K; R_0805_HandSoldering
R7: 200; R_0805_HandSoldering
R8, R9, R10, R11, R12: ?; R_0805_HandSoldering
R13, R14, R15: 1000; R_0805_HandSoldering
U1: LTC3225; DFN-10-1EP_2x3mm_Pitch0.5mm
U2: TPS61221DCKR; sc_70-6
U3: W25Q32FVSSIG; SOIC-8_3.9x4.9mm_Pitch1.27mm
U4: ESP8266EX; QFN-32-1EP_5x5mm_Pitch0.5mm
Y1: 26 MHz; Crystal_SMD_Abracon_ABM8G-4pin_3.2x2.5mm

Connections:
CHARGE_LED: D1.1 (K), U1.5 (PGOOD)
GND: AE1.1, C1.3 (-), C2.2, C4.2, C5.2, C6.2, C7.2, C11.2, C12.2, C13.2, C14.2, D2.1 (K), D3.1 (K), D4.1 (K), D5.1 (K), J1.A1 (GND), J1.B1 (GND), J1.B12 (GND), J6.1, J7.1, J8.1, R1.2, R3.2, R6.1, R15.2, U1.8 (GND), U2.3 (GND), U3.4 (GND), U4.33 (GND), Y1.2, Y1.4
MODE: J5.1, R13.1, U4.15 (GPIO0)
unnamed: AE1.2, C10.2, C13.1
unnamed: C1.1 (+), C2.1, L1.1, U1.10 (COUT), U2.1 (VIN), U2.6 (EN)
unnamed: C1.2 (B), U1.3 (CX)
unnamed: C3.1, U1.1 (C+)
unnamed: C3.2, U1.2 (C-)
unnamed: C6.1, U4.28 (XTAL_IN), Y1.1
unnamed: C7.1, U4.27 (XTAL_OUT), Y1.3
unnamed: C9.2, U4.1 (VddA)
unnamed: C10.1, C14.1, U4.2 (LNA/ANT)
unnamed: D1.2 (A), R8.2
unnamed: D2.2 (A), R9.2
unnamed: D3.2 (A), R10.2
unnamed: D4.2 (A), R11.2
unnamed: D5.2 (A), R12.2
unnamed: J3.1, U4.26 (UTXD)
unnamed: J4.1, U4.25 (URXD)
unnamed: L1.2, U2.5 (L)
unnamed: R1.1, U1.7 (PROG)
unnamed: R6.2, U4.31 (RES12K)
unnamed: R7.1, U3.6 (CLK)
unnamed: R7.2, U4.21 (SD_CLK)
unnamed: R9.1, U4.9 (MTMS/GPIO14)
unnamed: R10.1, U4.10 (MTDI/GPIO12)
unnamed: R11.1, U4.12 (MTCK/GPIO13)
unnamed: R12.1, U4.16 (GP4/VD)
unnamed: R14.1, U4.14 (GPIO2)
unnamed: R15.1, U4.13 (MTDO/GPIO15)
unnamed: U3.1 (/Cs), U4.20 (SD_CMD)
unnamed: U3.2 (DO), U4.22 (SD_D0)
unnamed: U3.3 (/WP), U4.19 (SD_D3)
unnamed: U3.5 (DI), U4.23 (SD_D1)
unnamed: U3.7 (/HOLD), U4.18 (SD_D2)
RST: C8.1, R4.2, U4.32 (EXT_RSTB)
USBRST: C8.2, J1.A12 (GND), J2.1, R5.2
USB_PWR: R2.1, R3.1, U4.8 (XPD_DCDC)
VBUS: C5.1, J1.A4 (VBUS), J1.A9 (VBUS), J1.B4 (VBUS), J1.B9 (VBUS), R2.2, R8.1, U1.4 (~SHDN), U1.6 (VSEL), U1.9 (VIN)
VDD: C4.1, C9.1, C11.1, C12.1, R4.1, R5.1, R13.2, R14.2, U2.2 (FB), U2.4 (VOUT), U3.8 (VCC), U4.3 (Vdd3P3), U4.4 (Vdd3P3), U4.7 (CHIP_EN), U4.11 (VddPST), U4.17 (VddPST), U4.29 (VDDD), U4.30 (VDDA)

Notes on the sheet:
Decoupling for LTC3225
Supercap Charger
Boost Converter
USB C Connector for Power Supply
Supercap
Microcontroller Periphery
SPI Flash Memory
Inter-Card Connector
Check if connected to USB
LED Interface
0805
±10PPM
±1%
>15mil
0603
0805
X5R/X7R 0805

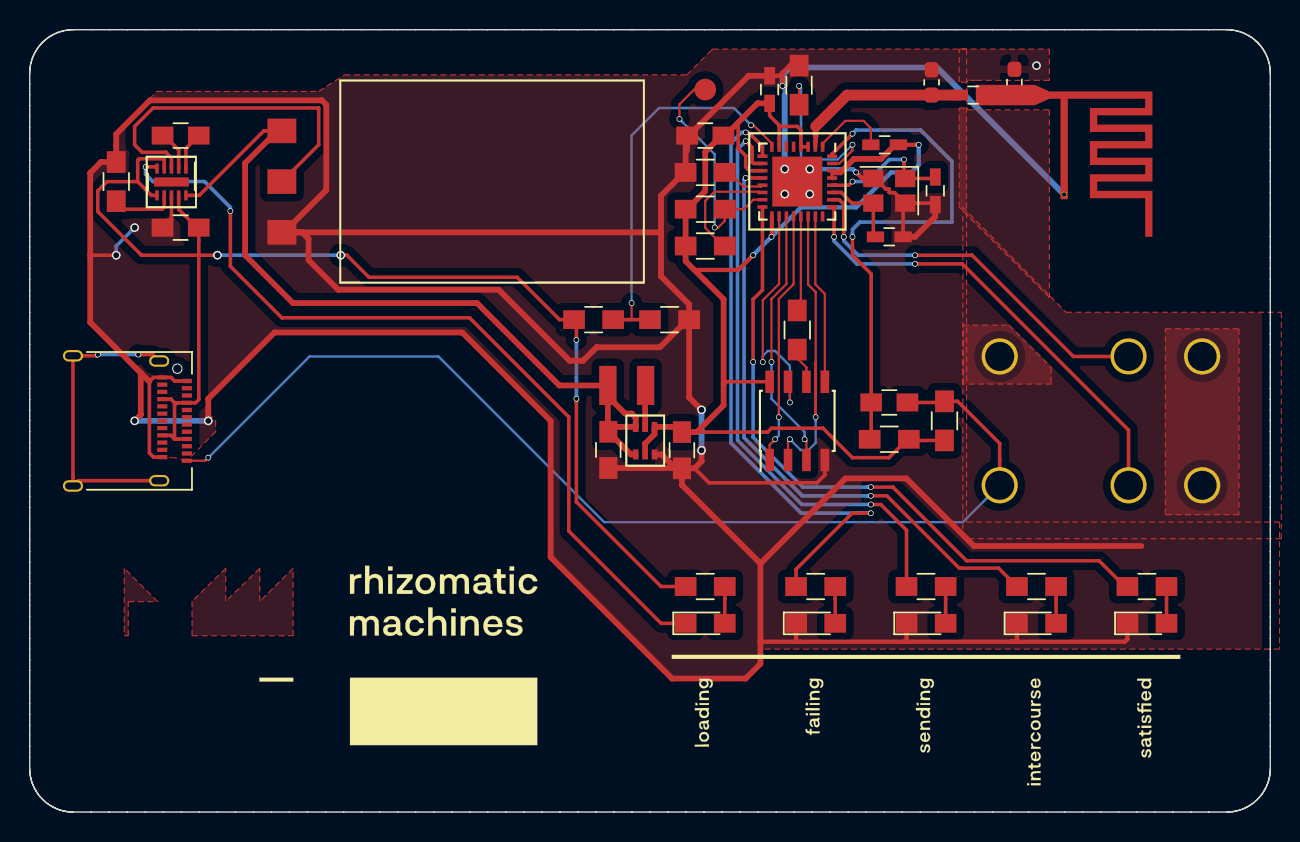
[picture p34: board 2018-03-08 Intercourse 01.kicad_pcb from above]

Board: 2 copper layers, 85.6 x 54.0 mm, 49 parts (0 on the bottom side), 40 nets.

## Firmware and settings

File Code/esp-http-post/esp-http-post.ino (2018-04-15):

#include <ESP8266HTTPClient.h>
#include <ESP8266WiFi.h>
#include <ArduinoJson.h>

String my_id = "f049cd234b5a445766394925a2f0c46961d526f2";
String secret_key = "genesis";
String other_id = "bd981973599153991c20a92552fd847a85614e77";

void setup() {

  Serial.begin(115200);             //Serial connection
  WiFi.begin("123geheim", "");      //WiFi connection

  while (WiFi.status() != WL_CONNECTED) {  //Wait for the WiFI connection completion

    delay(500);
    Serial.println("Waiting for connection");

  }
}

void loop() {

  if (WiFi.status() == WL_CONNECTED) { //Check WiFi connection status

    StaticJsonBuffer<300> JSONbuffer;   //Declaring static JSON buffer
    JsonObject& JSONencoder = JSONbuffer.createObject();

    JSONencoder["my_id"] = my_id; // card id
    JSONencoder["secret_key"] = secret_key; // password
    JSONencoder["other_id"] = other_id; // card id


    char JSONmessageBuffer[300];
    JSONencoder.prettyPrintTo(JSONmessageBuffer, sizeof(JSONmessageBuffer));
    Serial.println(JSONmessageBuffer);

    HTTPClient http;    //Declare object of class HTTPClient

    http.begin("http://www.rhizomaticmachines.com/api/v1/intercourse");      //Specify request destination
    http.addHeader("Content-Type", "application/json");  //Specify content-type header

    int httpCode = http.POST(JSONmessageBuffer);   //Send the request
    String payload = http.getString();                                        //Get the response payload

    Serial.println(httpCode);   //Print HTTP return code
    Serial.println(payload);    //Print request response payload

    http.end();  //Close connection

  } else {

    Serial.println("Error in WiFi connection");

  }

  delay(30000);  //Send a request every 30 seconds

}

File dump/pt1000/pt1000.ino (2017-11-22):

#include <Adafruit_MAX31865.h>

// Use software SPI: CS, DI, DO, CLK
Adafruit_MAX31865 max = Adafruit_MAX31865(10, 11, 12, 13);
// use hardware SPI, just pass in the CS pin
//Adafruit_MAX31865 max = Adafruit_MAX31865(10);

// The value of the Rref resistor. Use 430.0!
#define RREF 430.0


void setup() {
  Serial.begin(115200);
  Serial.println("Adafruit MAX31865 PT100 Sensor Test!");

  max.begin(MAX31865_2WIRE);  // set to 2WIRE or 4WIRE as necessary
}


void loop() {
  uint16_t rtd = max.readRTD();

  Serial.print("RTD value: "); Serial.println(rtd);
  float ratio = rtd;
  ratio /= 32768;
  Serial.print("Ratio = "); Serial.println(ratio,8);
  Serial.print("Resistance = "); Serial.println(RREF*ratio,8);
  Serial.print("Temperature = "); Serial.println(max.temperature(101, RREF));

  // Check and print any faults
  uint8_t fault = max.readFault();
  if (fault) {
    Serial.print("Fault 0x"); Serial.println(fault, HEX);
    if (fault & MAX31865_FAULT_HIGHTHRESH) {
      Serial.println("RTD High Threshold"); 
    }
    if (fault & MAX31865_FAULT_LOWTHRESH) {
      Serial.println("RTD Low Threshold"); 
    }
    if (fault & MAX31865_FAULT_REFINLOW) {
      Serial.println("REFIN- > 0.85 x Bias"); 
    }
    if (fault & MAX31865_FAULT_REFINHIGH) {
      Serial.println("REFIN- < 0.85 x Bias - FORCE- open"); 
    }
    if (fault & MAX31865_FAULT_RTDINLOW) {
      Serial.println("RTDIN- < 0.85 x Bias - FORCE- open"); 
    }
    if (fault & MAX31865_FAULT_OVUV) {
      Serial.println("Under/Over voltage"); 
    }
    max.clearFault();
  }
  Serial.println();
  delay(1000);
}

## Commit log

2018-03-07 created BOM
2018-03-07 updated BOM
2018-03-08 Add Kicad Project
    [2018-03-08 Intercourse 01.kicad_pcb, 2018-03-08 Intercourse 01.sch]
2018-03-13 Update Schematics
    * Add SPI Wiring
    [2018-03-08 Intercourse 01.sch]
2018-03-13 Update Schematics
    * Finish ESP8266EX
    [2018-03-08 Intercourse 01.sch]
2018-03-13 added spi flash
    [2018-03-08 Intercourse 01.sch]
2018-03-13 added supercap
    [2018-03-08 Intercourse 01.sch]
2018-03-13 added usb
    [2018-03-08 Intercourse 01.sch]
2018-03-15 added supercap charger
    [2018-03-08 Intercourse 01.sch]
2018-03-15 added charge pump into schematic
    [2018-03-08 Intercourse 01.sch]
2018-03-15 Update Schematic
    * Add missing Cap Values
    [2018-03-08 Intercourse 01.sch]
2018-03-15 charge pump done
    [2018-03-08 Intercourse 01.sch]
2018-03-16 added booster circuit to schematic
    [2018-03-08 Intercourse 01.sch]
2018-03-16 plain schematic finished and beautified
    [2018-03-08 Intercourse 01.sch]
2018-03-17 started adding dev and conn pins
    not complete
    [2018-03-08 Intercourse 01.sch]
2018-03-19 schematic edits
    * added NCs
    * clean up
    [2018-03-08 Intercourse 01.sch]
2018-03-19 clean up schematic
    * added connector
    * changed labels
    * made some stuff cleaner
    [2018-03-08 Intercourse 01.sch]
2018-03-19 further cleaning
    * cleaned up
    * added todos
    [2018-03-08 Intercourse 01.sch]
2018-03-19 added examle for ESP8266 schematic
2018-03-20 changes labels
    Because I like them better ...
    [2018-03-08 Intercourse 01.sch]
2018-03-21 added reset rc filter circuit
    [2018-03-08 Intercourse 01.sch]
2018-03-21 added leds to schematic
    [2018-03-08 Intercourse 01.sch]
2018-03-21 added usb c recaptable
    [2018-03-08 Intercourse 01.sch]
2018-03-21 Replace BOM Table with Mouser BOM Link
2018-03-21 changed open drain circuit on charger
    [2018-03-08 Intercourse 01.sch]
2018-03-21 corrected capacitors on esp8266ex
    [2018-03-08 Intercourse 01.sch]
2018-03-21 minor fixes
    [2018-03-08 Intercourse 01.sch]
2018-03-22 added esp8266 pin references
2018-03-22 finailzed schematic with annotations
    [2018-03-08 Intercourse 01.sch]
2018-03-22 Add Antenna Library
2018-03-22 updated library paths
    [2018-03-08 Intercourse 01.sch]
2018-03-22 created additional footprints and completed footprint reference
    [2018-03-08 Intercourse 01.sch]
2018-03-23 created netlist and created pcb
    [2018-03-08 Intercourse 01.sch]
2018-03-23 plotted schematic
2018-03-23 started pcb layout
    [2018-03-08 Intercourse 01_alex.kicad_pcb, cc.dxf]
2018-03-24 backup of layouting process
    [2018-03-08 Intercourse 01.kicad_pcb, 2018-03-08 Intercourse 01.sch, 2018-03-08 Intercourse 01_alex.kicad_pcb]
2018-03-24 added link to kicad designing
2018-03-24 backup pcb layout
    [2018-03-08 Intercourse 01.kicad_pcb]
2018-03-25 advanced layout, backuping
    [2018-03-08 Intercourse 01.kicad_pcb]
2018-03-25 ready to route
    [2018-03-08 Intercourse 01.kicad_pcb, 2018-03-08 Intercourse 01.sch]
2018-03-26 layout 01 before drc
    [2018-03-08 Intercourse 01.kicad_pcb]
2018-03-26 drc complete
    [2018-03-08 Intercourse 01.kicad_pcb]
2018-03-27 created graphic layout and edited it into pcb
    [2018-03-08 Intercourse 01.kicad_pcb, logo_01.dxf]
2018-03-27 logo fix
    [2018-03-08 Intercourse 01.kicad_pcb]
2018-03-27 gerber files
    [2018-03-08 Intercourse 01-B.Adhes.gbr, 2018-03-08 Intercourse 01-B.CrtYd.gbr, 2018-03-08 Intercourse 01-B.Cu.gbr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]
2018-03-27 don't know what I changed
    [2018-03-08 Intercourse 01.kicad_pcb]
2018-03-31 major cleanup and moving around
    [2018-03-08 Intercourse 01-B.Adhes.gbr, 2018-03-08 Intercourse 01-B.CrtYd.gbr, 2018-03-08 Intercourse 01-B.Cu.gbr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]
2018-04-07 FIX 2 PCBnew Errors
    * Supercap + -> Henry
    * SupercapCharger GND Connection
    [2018-03-08 Intercourse 01.kicad_pcb]
2018-04-09 clean pcb is fine
    [2018-03-08 Intercourse 01.kicad_pcb]
2018-04-09 added layout and created gerber files
    [2018-03-08 Intercourse 01-B.Adhes.gbr, 2018-03-08 Intercourse 01-B.CrtYd.gbr, 2018-03-08 Intercourse 01-B.Cu.gbr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]
2018-04-10 Add USBRST Connection on .sch & .pcb
    [2018-03-08 Intercourse 01.kicad_pcb, 2018-03-08 Intercourse 01.sch]
2018-04-10 rev3 fixed via position
    [2018-03-08 Intercourse 01-B.Adhes.gbr, 2018-03-08 Intercourse 01-B.CrtYd.gbr, 2018-03-08 Intercourse 01-B.Cu.gbr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]
2018-04-12 Update Links
    * Add RF PCB Guidelines Link
2018-04-16 Dataviz and Clean Up
    [rhizm_layout_1_footprint_logo-front.dxf]
2018-11-23 add kicad screen
2019-05-19 update and antenna
    - drawn antenna component and footprint
    - backup before changing the schematics and layout
    [2018-03-08 Intercourse 01-2019-05-18-23-53-05.sch]
2019-05-19 updated antenna design
    board ready for revision
    [2018-03-08 Intercourse 01-2019-05-19-12-40-07.sch, 2018-03-08 Intercourse 01-2019-05-19-12-44-41.sch, 2018-03-08 Intercourse 01.kicad_pcb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]
2019-05-20 updated antenna design
    - had to move components also
    [2018-03-08 Intercourse 01.kicad_pcb]
2019-05-23 rev4 ready for review
    - added parts to antenna trace
    - created gerber files
    [2018-03-08 Intercourse 01-B_Adhes.gbr, 2018-03-08 Intercourse 01-B_CrtYd.gbr, 2018-03-08 Intercourse 01-B_Cu.gbr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]
2019-06-13 bom & pos files
    [bom_rm.xlsx]
